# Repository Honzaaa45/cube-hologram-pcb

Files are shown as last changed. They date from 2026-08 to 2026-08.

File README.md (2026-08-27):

<div align="center">

<picture>
  <source media="(prefers-color-scheme: dark)" srcset="docs/media/banner-dark.svg">
  <source media="(prefers-color-scheme: light)" srcset="docs/media/banner-light.svg">
  CUBE — afficheur holographique Pepper's Ghost
</picture>

# CUBE

**Carte électronique d'un afficheur holographique de bureau — conçue entièrement par du code, vérifiée automatiquement.**









</div>

---

## Aperçu

Le circuit imprimé, rendu depuis les fichiers de ce dépôt. Fond transparent : lisible en thème clair comme en thème sombre.

<div align="center">
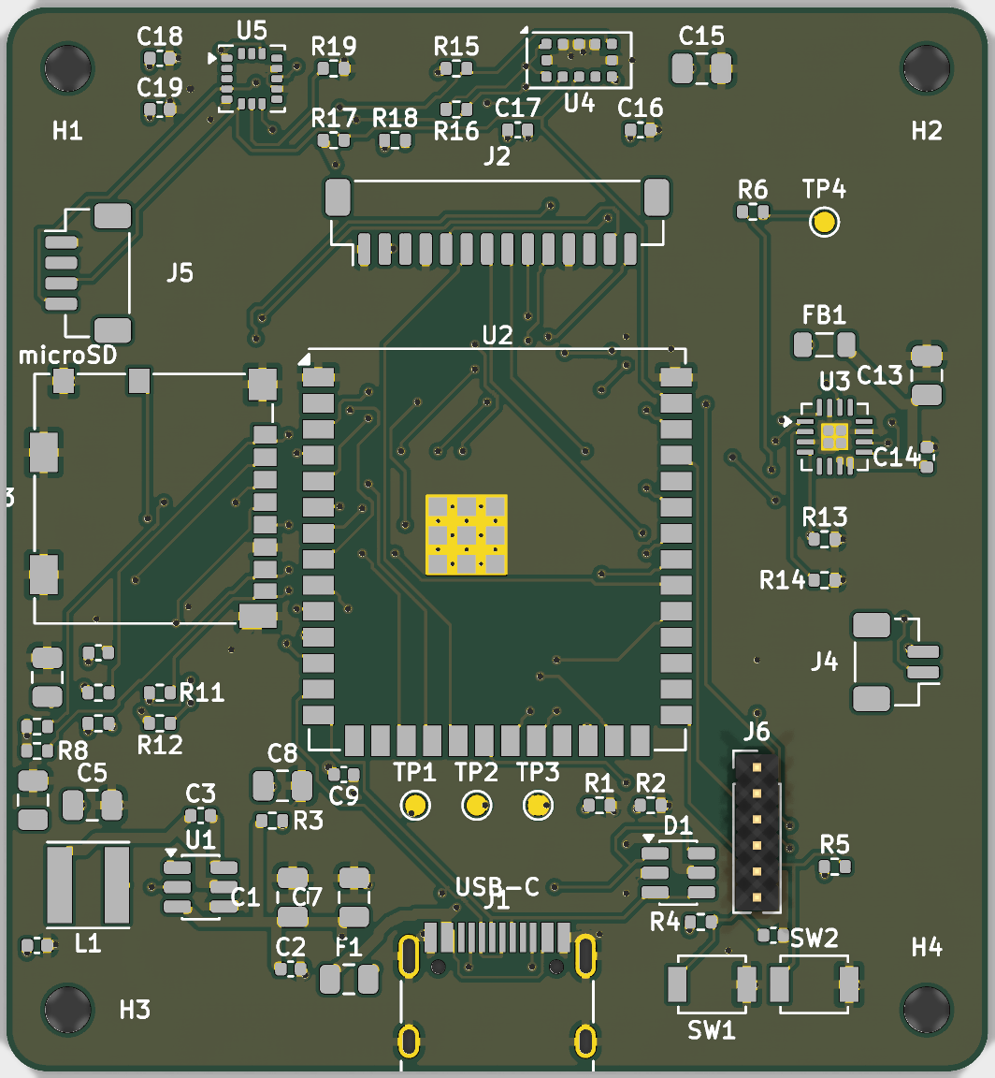
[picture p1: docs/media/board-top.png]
Carte CUBE vue de dessus
  
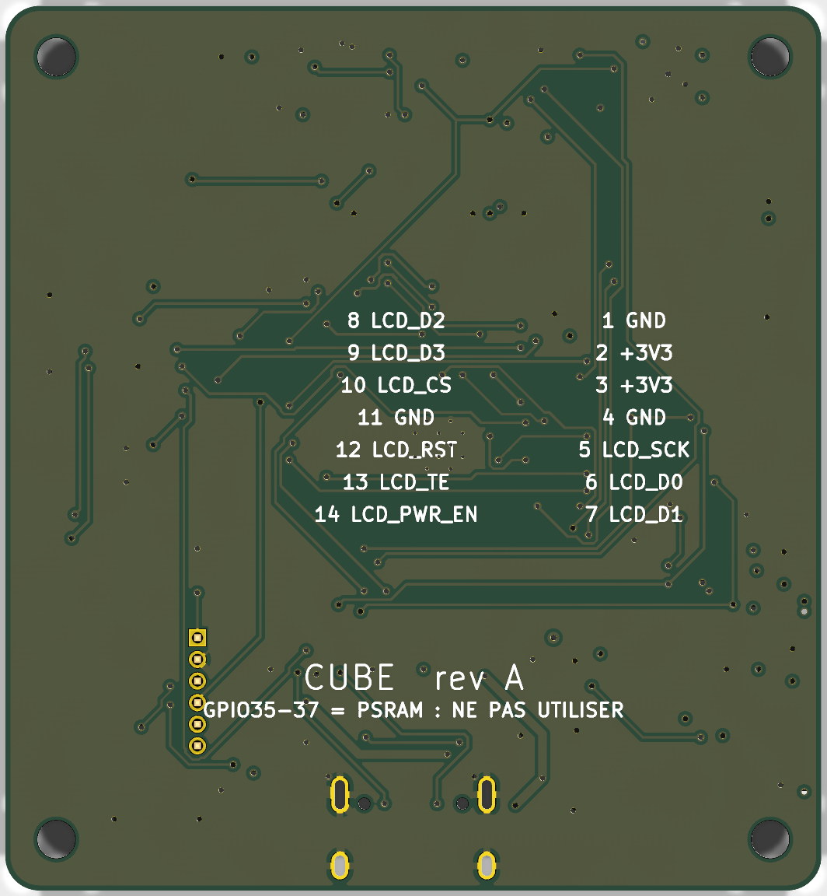
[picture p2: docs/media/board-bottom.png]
Carte CUBE vue de dessous
  
</div>

> [!NOTE]
> **La carte n'a pas encore été fabriquée.** Les images ci-dessus sont des rendus 3D produits par KiCad
> à partir des fichiers du dépôt, pas des photos. L'emplacement `docs/media/demo.gif` est réservé pour
> la démonstration du prototype physique — voir [ce qu'il reste à faire](#état-davancement).

## Pourquoi ce projet

Les afficheurs « holographiques » DIY qu'on trouve en ligne se ressemblent tous : un ESP32, un petit écran
OLED monochrome et une breadboard. Le résultat est saccadé, minuscule, et l'électronique est visible.
Ce projet répond à la même envie mais en produit final : image couleur fluide, électronique intégrée sur
une carte sur mesure, et surtout une conception **vérifiable** plutôt que dessinée à la main.

## Le principe optique

L'illusion s'appelle *Pepper's Ghost*. Une dalle posée à plat éclaire un cube séparateur de faisceau ;
la lame à 45° à l'intérieur du cube renvoie l'image vers l'observateur, qui la voit flotter dans le verre.

**La conséquence, et c'est tout le projet :** en Pepper's Ghost, **le noir de l'image est la transparence**.
Un écran LCD, dont le noir est gris, ferait flotter un rectangle lumineux autour du sujet. Un pixel AMOLED
éteint n'émet rien, donc disparaît vraiment. Ce constat commande l'ensemble des choix matériels.

## Architecture

Ce dépôt n'est pas un projet KiCad : c'est une **chaîne de génération** dont KiCad est la sortie.
`design.py` est la seule source de vérité ; tout le reste en découle et se recalcule.

```mermaid
flowchart TD
    D["design.py<br/>source unique de vérité<br/>63 composants · 46 nets · 223 connexions"]

    D --> GS["gen_sch.py"]
    D --> PL["place.py<br/>solveur de placement"]
    D --> GD["gen_docs.py"]

    PL --> RT["router.py<br/>labyrinthe Dijkstra + couture des plans"]
    RT --> CL["cleanup.py<br/>passe de finition"]
    CL --> RJ["routes.json"]
    RJ --> GP["gen_pcb.py"]
    D --> GP

    GS --> SCH["cube.kicad_sch"]
    GP --> PCB["cube.kicad_pcb"]
    PCB --> FZ["fill_zones.py<br/>remplissage des plans"]

    SCH --> V["validate.py + check_cad.py"]
    FZ --> V
    V --> OK{{"ERC 0 erreur<br/>DRC 0 violation<br/>parité 0 écart"}}

    FZ --> GF["gen_fab.py"]
    GF --> FAB["gerbers · CPL · STEP · rendus"]
    GD --> DOC["docs/CARTE.md"]

    OK -.->|"rejoué à chaque push"| CI["GitHub Actions"]
```

<details>
<summary><b>Architecture matérielle de la carte</b> (cliquer pour dérouler)</summary>

```mermaid
flowchart LR
    USB["USB-C<br/>5 V"] --> F["Fusible PPTC<br/>+ ESD USBLC6"]
    F --> BK["AP63203WU<br/>buck 2 A → 3,3 V"]
    BK --> MCU
    F -.->|"USB natif D+/D−"| MCU

    MCU["ESP32-S3-WROOM-1U<br/>N16R8<br/>16 MB flash · 8 MB PSRAM octale"]

    MCU -->|"QSPI + TE"| LCD["J2 — dalle AMOLED<br/>JST-SH 14 pts"]
    MCU -->|"SDIO 4 bits"| SD["microSD"]
    MCU -->|"I2S"| FB["Ferrite"] --> AMP["MAX98357A"] --> SPK["Haut-parleur"]
    MCU -->|"I2C"| TOF["VL53L1X<br/>0x29"]
    MCU -->|"I2C"| ACC["LIS3DH<br/>0x18"]
    MCU -->|"UART0 + BOOT/EN"| DBG["J6 — debug"]
```

</details>

## Démarrage rapide

Il faut **Python 3.9+** et **KiCad 9** installé : les scripts lisent ses bibliothèques officielles de
symboles et d'empreintes. Aucune dépendance Python à installer pour la vérification.

```bash
git clone https://github.com/Honzaaa45/cube-hologram-pcb.git
```

```bash
cd cube-hologram-pcb
```

Vérifier que la conception est cohérente (14 contrôles, ~2 s) :

```bash
python tools/validate.py
```

Rejouer l'ERC, le DRC et le contrôle de parité schéma/PCB :

```bash
python tools/check_cad.py
```

Ouvrir le projet dans KiCad :

```bash
kicad hw/cube.kicad_pro
```

<details>
<summary><b>Régénérer toute la CAO depuis <code>design.py</code></b></summary>

Le schéma et le PCB sont des **sorties**. Après avoir modifié `tools/design.py` :

```bash
python tools/gen_project.py
```

```bash
python tools/gen_sch.py
```

```bash
python tools/gen_pcb.py
```

Si le placement a changé, relancer le solveur puis le routeur (≈ 8 min) :

```bash
python tools/place.py
```

```bash
python tools/router.py
```

Puis remplir les plans de cuivre. **Cette étape n'est pas optionnelle** : sans elle, le DRC voit les
zones vides et signale à tort toutes les pastilles de masse comme non connectées.

```bash
"C:\Program Files\KiCad\9.0\bin\python.exe" tools/fill_zones.py
```

Enfin, produire les fichiers de fabrication :

```bash
python tools/gen_fab.py
```

Si KiCad n'est pas détecté automatiquement, renseignez `KICAD_SHARE` et `KICAD_CLI` — voir
[`.env.example`](.env.example).

</details>

## La carte en bref

| | |
|---|---|
| Microcontrôleur | ESP32-S3-WROOM-1U-N16R8 — 16 MB flash, **8 MB PSRAM octale**, antenne U.FL |
| Écran | connecteur QSPI générique 14 points (JST-SH 1,0 mm), **broche TE câblée** |
| Stockage | microSD en SDIO 4 bits |
| Audio | MAX98357A, ampli classe D I2S mono |
| Capteurs | VL53L1X (temps de vol) + LIS3DH (accéléromètre) |
| Alimentation | USB-C 5 V → AP63203WU, buck 2 A sortie 3,3 V fixe |
| Circuit imprimé | **48 × 52 mm**, 4 couches, 63 composants, montage sur une seule face |
| Empilage | F.Cu / plan de masse / plan +3V3 / B.Cu |

Le détail complet — table des GPIO, brochages des connecteurs, bilan de consommation, cotes pour
Fusion 360 et nomenclature — est dans **[`docs/CARTE.md`](docs/CARTE.md)**.

## Stack et arborescence

**Python 3** (bibliothèque standard uniquement pour la génération) · **KiCad 9** (bibliothèques et
`kicad-cli`) · **ruff** pour le lint · **GitHub Actions** pour la vérification continue.

```
tools/                  chaîne de génération — aucune dépendance externe
  design.py               SOURCE UNIQUE DE VÉRITÉ : composants, netlist, placement
  sexpr.py                lecteur/écrivain de S-expressions KiCad, écrit à la main
  symlib.py               accès aux bibliothèques officielles KiCad 9
  fputil.py               géométrie des empreintes (courtoisie, pastilles, rotation)
  kicadpath.py            localise KiCad sans chemin codé en dur
  place.py                solveur de placement par relaxation sous contraintes
  router.py               routeur labyrinthe (Dijkstra 8 directions) + couture des plans
  cleanup.py              passe de finition sur les liaisons restantes
  import_routes.py        recapture dans routes.json le routage fait a la main
  gen_sch.py              produit hw/cube.kicad_sch
  gen_pcb.py              produit hw/cube.kicad_pcb
  gen_project.py          produit le projet KiCad et les tables de bibliothèques
  fill_zones.py           remplit les plans avec le moteur officiel de KiCad
  gen_fab.py              gerbers, perçage, CPL, STEP, rendus, PDF
  gen_docs.py             produit docs/CARTE.md
  gen_social.py           produit l'aperçu social
  validate.py             14 contrôles de cohérence  ← lancé par la CI
  check_cad.py            verrou de non-régression ERC/DRC  ← lancé par la CI

hw/                     projet KiCad 9 (fichiers générés, mais versionnés)
  cube.kicad_pro          projet : classes de nets, règles de conception
  cube.kicad_sch          schéma, feuille A2, 7 blocs
  cube.kicad_pcb          circuit imprimé 4 couches, plans remplis
  cube.kicad_sym          symbole maison : lecteur microSD Molex 104031-0811
  routes.json             pistes et vias produits par le routeur
  erc.rpt / drc.rpt       rapports de vérification, régénérables
  fab/                    sorties prêtes à commander (gerbers, CPL, STEP, PDF)

docs/
  CARTE.md                fiche technique complète
  media/                  bannières animées, rendus, aperçu social
```

## Décisions techniques

Cinq choix qui expliquent la carte. Pour chacun : la raison, et ce qui a été écarté.

<details open>
<summary><b>1. AMOLED plutôt qu'un IPS SPI</b></summary>

En Pepper's Ghost, le noir affiché **est** la transparence. Le noir d'un LCD est un gris à environ
1000:1 de contraste : le spectateur verrait un rectangle lumineux flotter autour du sujet, et
l'illusion s'effondre. Un pixel AMOLED éteint n'émet rien.

*Écarté :* un IPS SPI (ST7789 ou GC9A01), deux à trois fois moins cher et bien plus documenté. Aucun
gain de fluidité ni de résolution ne compense un fond visible.
</details>

<details>
<summary><b>2. Module WROOM-1U plutôt que le MINI-1, réputé plus petit</b></summary>

Mesures faites avant de trancher : WROOM-1U = 18,0 × 19,2 mm (346 mm²), MINI-1 = 15,4 × 20,5 mm
(316 mm²). Le MINI-1 n'est que **9 % plus petit en surface** — et il est 1,3 mm **plus long**. En
échange on perdrait la PSRAM octale, donc la moitié de la bande passante disponible pour un
framebuffer. De toute façon, ce n'est pas le module qui dimensionne la carte : ce sont l'USB-C, le
connecteur écran et les trous de fixation.

*Écarté :* ESP32-S3-MINI-1-N8 (8 MB flash, aucune PSRAM) et la puce nue ESP32-S3FH4R2 (49 mm², mais
elle impose design RF, quartz, antenne accordée et recertification).
</details>

<details>
<summary><b>3. Un convertisseur à découpage, pas un régulateur linéaire</b></summary>

Bilan en pointe du rail 3,3 V : ESP32-S3 en émission WiFi (355 mA) + dalle AMOLED plein blanc
(~250 mA) + écriture microSD (~100 mA) ≈ 900 mA. Un LDO 5 V → 3,3 V y dissiperait environ 1 W —
dans un boîtier fermé et opaque, à côté d'un capteur de distance.

*Écarté :* un LDO 1 A type AP7361C, plus simple (trois composants au lieu de six) et sans bruit de
découpage. Le calcul thermique tranche.
</details>

<details>
<summary><b>4. L'amplificateur audio alimenté en 3,3 V, pas en 5 V</b></summary>

Le MAX98357A accepte 2,5 à 5,5 V, et 5 V donnerait plus de puissance acoustique. Mais ses seuils
logiques se réfèrent à son alimentation : piloter en 3,3 V une puce alimentée en 5 V place les
niveaux I2S dans une zone non garantie. La carte l'alimente donc en 3,3 V, derrière une perle de
ferrite qui isole son rail de celui du microcontrôleur.

*Écarté :* 5 V avec un adaptateur de niveau (composant et surface en plus, pour une puissance dont un
objet de bureau n'a pas l'usage).
</details>

<details>
<summary><b>5. Une CAO générée par code plutôt que dessinée à la main</b></summary>

C'est le choix structurant du dépôt. `design.py` décrit l'intention ; les scripts produisent le
schéma et le circuit imprimé ; puis un script **compare la netlist réellement exportée par KiCad à
cette intention, connexion par connexion** — 223 sur 223, zéro divergence. La CI rejoue l'ERC, le DRC
et le contrôle de parité à chaque push.

Le bénéfice n'est pas la vitesse : dessiner à la main aurait été plus rapide au départ. C'est de
pouvoir **prouver** que le schéma est juste, et de tout régénérer après un changement sans reprendre
le travail. C'est aussi ce qui a permis de détecter, pendant le développement, que la table des GPIO
documentait `LCD_SCK` là où le netlist portait `LCD_SCK_MCU` — une résistance série séparait les deux.

*Écarté :* KiCad en interactif, l'approche normale et parfaitement légitime. Elle ne donne aucun
moyen de démontrer la cohérence, ni de rejouer la conception.
</details>

## État d'avancement

**Fait et vérifié :**

| Contrôle | Résultat |
|---|---|
| ERC du schéma | **0 erreur** (1 avertissement connu, documenté ci-dessous) |
| Netlist exportée comparée à l'intention | **223 / 223 connexions, 0 divergence** |
| Parité schéma ↔ PCB, vérifiée par KiCad | **0 écart** |
| Placement (contours de courtoisie) | **0 chevauchement**, toutes les pastilles sur la carte |
| DRC du circuit imprimé | **0 violation** |
| Routage | **223 / 223 connexions** |
| Sorties de fabrication | gerbers 4 couches, perçage, CPL, STEP, rendus, PDF |

L'unique avertissement ERC : le pad thermique du MAX98357A est typé « Unspecified » dans la
bibliothèque KiCad officielle et relié à GND. Le comportement est correct, c'est le typage amont qui
est imprécis.

**Intégration continue :** le workflow [`.github/workflows/ci.yml`](.github/workflows/ci.yml) rejoue à
chaque push le lint, la validation de la netlist, puis l'ERC, le DRC et le contrôle de parité sur une
installation KiCad 9 fraîche. Les commandes qu'il exécute sont exactement `python tools/validate.py`
et `python tools/check_cad.py` : elles se lancent à l'identique en local, et c'est là qu'ont été
obtenus les résultats du tableau ci-dessus.

**Routage terminé.** Les 4 dernières liaisons — autour du LIS3DH, boîtier LGA-16 au pas de 0,5 mm —
ont été tirées à la main dans Pcbnew, puis réinjectées dans `hw/routes.json` par
`tools/import_routes.py` : le routage manuel fait désormais partie du pipeline et survit à une
régénération. Restent 8 avertissements de sérigraphie purement cosmétiques (texte rogné là où il
croise une pastille ou le bord), sans effet fonctionnel.

**Limites connues — à lire avant de vous en servir :**

- ⚠️ **La carte n'a jamais été fabriquée ni testée physiquement.** Tout ce qui est affirmé ici est
  vérifié *en CAO*. Une revue humaine reste indispensable avant de commander.
- Le **firmware n'existe pas** : ce dépôt ne contient que le matériel et sa chaîne de génération.
- Le **boîtier n'est pas modélisé** ; `docs/CARTE.md` fournit les cotes nécessaires pour Fusion 360.
- Le routeur maison ne fait **pas de rip-up local**, seulement un réordonnancement global sur quatre
  passes. C'est ce qui explique les 4 liaisons restantes.
- La chaîne est **testée sous Windows** avec KiCad 9.0.7. La détection de KiCad gère Linux et macOS
  mais n'y a pas été éprouvée ; la CI, elle, tourne bien sous Ubuntu.

## Licences

Deux licences, parce que ce dépôt contient deux natures de travail :

- **Code** (`tools/`, CI, scripts) — [MIT](LICENSE).
- **Matériel** (`hw/`, schéma, circuit imprimé, fichiers de fabrication) —
  [CERN-OHL-S-2.0](LICENSE-HARDWARE), la licence matérielle libre fortement réciproque du CERN : qui
  distribue un produit dérivé de cette carte doit en publier les sources de conception.

## Auteur

**Honza** — [@Honzaaa45](https://github.com/Honzaaa45)
Étudiant en BUT GEII, parcours Automatisme et Informatique Industrielle.

Les contributions sont bienvenues, en particulier sur le routeur : voir
[CONTRIBUTING.md](CONTRIBUTING.md).

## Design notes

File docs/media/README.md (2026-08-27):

# Ressources visuelles

| Fichier | Origine | Régénération |
|---|---|---|
| `banner-light.svg` / `banner-dark.svg` | Bannière animée (SMIL), écrite à la main. Schéma optique Pepper's Ghost : dalle, cube séparateur, lame à 45°, rayons, image virtuelle. | manuelle |
| `board-top.png` / `board-bottom.png` | Rendus 3D KiCad, **fond transparent** pour rester lisibles sur les deux thèmes GitHub. | `python tools/gen_fab.py` |
| `social.png` | Aperçu social 1280 × 640 (GitHub, LinkedIn, Slack). | `python tools/gen_social.py` |
| `demo.gif` | **Manquant.** Réservé à la démonstration du prototype physique. | à filmer — voir ci-dessous |

## Ce qu'il faut filmer pour `demo.gif`

La carte n'est pas encore fabriquée : cette démonstration ne peut pas exister aujourd'hui.
Quand le prototype fonctionnera, capturer une boucle de **6 à 10 secondes**, en **800 × 600** ou moins,
sous **8 Mo** (limite d'affichage confortable sur GitHub) :

1. **Plan large, 2 s** — l'objet posé sur un bureau, boîtier fermé, dans une pièce peu éclairée.
   C'est l'obscurité relative qui rend l'illusion crédible.
2. **Plan serré sur le cube, 4 s** — l'animation qui flotte à l'intérieur. Filmer légèrement de côté
   puis se déplacer : c'est le déplacement du point de vue qui prouve que l'image flotte réellement,
   une vue fixe pourrait passer pour un autocollant.
3. **Fin, 2 s** — la main qui s'approche pour déclencher le capteur de distance, si cette fonction est
   implémentée dans le firmware.

Contraintes de prise de vue : trépied obligatoire (l'illusion supporte mal le tremblement), pas de
lumière directe sur la face avant du cube, et **ne pas filmer en contre-jour** — le halo parasite
détruirait le noir dont dépend tout l'effet.

Conversion depuis une vidéo :

```bash
ffmpeg -i demo.mp4 -vf "fps=15,scale=800:-1:flags=lanczos,split[a][b];[a]palettegen[p];[b][p]paletteuse" -loop 0 docs/media/demo.gif
```

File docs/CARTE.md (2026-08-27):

# CUBE — carte electronique

Carte mere de l'afficheur holographique Pepper's Ghost.

| | |
|---|---|
| MCU | ESP32-S3-WROOM-1U-N16R8 — 16 MB flash, 8 MB PSRAM **octale**, antenne U.FL |
| Ecran | connecteur QSPI generique 14 points, JST-SH 1,0 mm (J2) |
| Stockage | microSD en **SDIO 4 bits** (J3) |
| Audio | MAX98357A, ampli classe D I2S mono (U3) |
| Capteurs | VL53L1X (ToF, 0x29) + LIS3DH (accelerometre, 0x18) |
| Alimentation | USB-C 5 V -> AP63203WU, buck 2 A sortie 3,3 V fixe |
| Carte | 48.0 x 52.0 mm, **4 couches**, composants sur la face avant uniquement |

## Empilage

| Couche | Role |
|---|---|
| F.Cu | signaux + plan de masse de remplissage |
| In1.Cu | **plan de masse plein** — reference de retour du bus QSPI |
| In2.Cu | **plan +3V3** |
| B.Cu | signaux + plan de masse de remplissage |

Le bus QSPI de l'ecran est route sur F.Cu, directement au-dessus du plan de
masse In1 : c'est ce qui donne un chemin de retour court et propre a 80 MHz.

## Reperes mecaniques

Le repere du plan de masse (coordonnees KiCad) :

* `y = 100.0` — **avant** du boitier : le VL53L1X (U4) vise vers le haut, a
  travers une petite fenetre transparente aux infrarouges, devant l'ecran.
* `y = 152.0` — **arriere** : sortie USB-C.
* `x = 100.0` — **flanc gauche** : trappe microSD.
* 4 trous M2 (103.0 / 145.0 en X, 103.0 / 149.0 en Y), inserts a chaud
  recommandes cote boitier.

## Cotes pour le boitier (Fusion 360)

Origine = **coin haut-gauche de la carte** (le coin avant-gauche), axe X vers la droite, axe Y vers l'arriere.

* Contour : rectangle **48 x 52 mm**, coins arrondis R2.0 mm.
* Epaisseur du circuit imprime : 1,6 mm.
* Trous M2 (diametre 2,2 mm) a **3,0 mm** de chaque bord, soit (3,0 / 3,0), (45.0 / 3,0), (3,0 / 49.0), (45.0 / 49.0).
* La prise USB-C **deborde de 1.7 mm** au-dela du bord arriere : prevoir la decoupe correspondante dans le boitier.

| Ref | Role | Centre (x, y) | Emprise X | Emprise Y |
|---|---|---|---|---|
| J1 | USB-C | 24.00, 49.50 | 18.68 .. 29.32 | 44.23 .. 53.65 |
| J3 | microSD | 7.20, 24.00 | 0.65 .. 13.70 | 17.16 .. 30.84 |
| J2 | ECRAN QSPI | 24.00, 10.50 | 15.10 .. 32.90 | 7.90 .. 13.10 |
| J4 | HP | 43.50, 32.00 | 40.90 .. 46.10 | 29.10 .. 34.90 |
| J5 | I2C EXT | 4.00, 13.00 | 1.40 .. 6.60 | 9.10 .. 16.90 |
| J6 | DEBUG | 36.70, 37.15 | 35.15 .. 38.25 | 36.01 .. 44.64 |
| U2 | ESP32-S3-WROOM-1U-N16R8 | 24.00, 26.50 | 14.25 .. 33.75 | 16.65 .. 36.80 |
| U4 | VL53L1X | 28.00, 2.60 | 25.30 .. 30.70 | 1.10 .. 4.10 |
| SW1 | RESET | 34.50, 47.75 | 32.10 .. 36.90 | 46.10 .. 49.40 |
| SW2 | BOOT | 39.50, 47.75 | 37.10 .. 41.90 | 46.10 .. 49.40 |

Hauteurs a prevoir au-dessus de la carte (les plus contraignantes) :

| Composant | Hauteur approx. |
|---|---|
| Connecteurs JST-SH verticaux (J2, J4, J5) | ~4,3 mm nu, ~6 mm avec le connecteur femelle engage |
| Module ESP32-S3-WROOM-1U | 3,2 mm + le connecteur U.FL et son cable |
| Prise USB-C | 3,2 mm |
| Inductance L1 | 2,0 mm |
| Lecteur microSD | 1,9 mm |

Compter **8 mm de degagement** au-dessus de la carte pour etre tranquille.

> Le VL53L1X (U4) est en surface et **vise vers le haut**, perpendiculairement
> a la carte. Il lui faut une petite fenetre transparente aux infrarouges dans
> le plateau superieur, en avant de l'ecran, avec un entrefer maitrise. Si cela
> gene le design du boitier, ne pas monter U4 et brancher a la place un module
> ToF tout fait sur le port J5, positionne librement.

## Affectation des GPIO

| GPIO | Broche module | Net | Role |
|---|---|---|---|
| IO12 | 20 | LCD_SCK_MCU | Horloge QSPI, devient LCD_SCK apres R6 |
| IO11 | 19 | LCD_D0 | Donnee QSPI 0 |
| IO13 | 21 | LCD_D1 | Donnee QSPI 1 |
| IO14 | 22 | LCD_D2 | Donnee QSPI 2 |
| IO10 | 18 | LCD_D3 | Donnee QSPI 3 |
| IO9 | 17 | LCD_CS | Selection ecran |
| IO8 | 12 | LCD_RST | Reset ecran |
| IO18 | 11 | LCD_TE | Tearing Effect - synchro anti-dechirure |
| IO17 | 10 | LCD_PWR_EN | Activation alimentation dalle |
| IO39 | 32 | SD_CLK | Horloge SDIO |
| IO38 | 31 | SD_CMD | Commande SDIO |
| IO40 | 33 | SD_D0 | Donnee SDIO 0 |
| IO41 | 34 | SD_D1 | Donnee SDIO 1 |
| IO42 | 35 | SD_D2 | Donnee SDIO 2 |
| IO21 | 23 | SD_D3 | Donnee SDIO 3 |
| IO47 | 24 | SD_DET | Detection de carte |
| IO5 | 5 | I2S_BCLK | Horloge bit I2S |
| IO6 | 6 | I2S_LRCLK | Horloge mot I2S |
| IO7 | 7 | I2S_DOUT | Donnee I2S |
| IO15 | 8 | AMP_EN | Activation ampli (bas = eteint) |
| IO1 | 39 | I2C_SDA | I2C donnee |
| IO2 | 38 | I2C_SCL | I2C horloge |
| IO16 | 9 | TOF_XSHUT | Reset du VL53L1X |
| IO4 | 4 | TOF_INT | Interruption ToF |
| IO48 | 25 | ACC_INT1 | Interruption accelerometre |
| IO19 | 13 | USB_D- | USB natif |
| IO20 | 14 | USB_D+ | USB natif |
| IO43 | 37 | UART_TX | Console de debug |
| IO44 | 36 | UART_RX | Console de debug |
| IO0 | 27 | BOOT | Strapping - bouton BOOT |
| IO35 | 28 | -- INTERDIT | PSRAM octale (N16R8) |
| IO36 | 29 | -- INTERDIT | PSRAM octale (N16R8) |
| IO37 | 30 | -- INTERDIT | PSRAM octale (N16R8) |
| IO3 | 15 | libre | Strapping JTAG - laisse non connecte |
| IO45 | 26 | libre | Strapping VDD_SPI - laisse non connecte |
| IO46 | 16 | libre | Strapping log ROM - laisse non connecte |

> **GPIO35, 36 et 37 sont consommes par la PSRAM octale du N16R8.** Ils ne
> sont sortis nulle part sur cette carte et ne doivent jamais etre configures
> par le firmware. GPIO3, 45 et 46 sont des broches de strapping, laissees
> volontairement non connectees.

## J2 — connecteur ecran QSPI (JST-SH 1,0 mm, 14 points)

| Broche | Signal |
|---|---|
| 1 | GND |
| 2 | +3V3 |
| 3 | +3V3 |
| 4 | GND |
| 5 | LCD_SCK |
| 6 | LCD_D0 |
| 7 | LCD_D1 |
| 8 | LCD_D2 |
| 9 | LCD_D3 |
| 10 | LCD_CS |
| 11 | GND |
| 12 | LCD_RST |
| 13 | LCD_TE |
| 14 | LCD_PWR_EN |

L'ordre a ete choisi pour la qualite du signal : alimentation et masse
groupees en tete, les quatre lignes de donnees et l'horloge au milieu encadrees
par des masses, les commandes lentes en fin de connecteur.

`LCD_TE` est la broche *Tearing Effect* de la dalle. La cabler est ce qui
permet de synchroniser l'envoi d'une trame sur le balayage et d'obtenir zero
dechirure. C'est le detail qui separe un rendu propre d'un rendu « presque ».

`R6` est une resistance serie de 0 ohm sur `LCD_SCK`. Si l'horloge sonne sur
un cable ruban un peu long, la remplacer par 22 ohms.

## Autres connecteurs

| Ref | Nom | Type | Brochage |
|---|---|---|---|
| J4 | HP | JST-SH 2 pts | 1 = SPK_P, 2 = SPK_N. Sortie pontee : ne jamais relier une sortie a la masse. |
| J5 | I2C EXT | JST-SH 4 pts | 1 = GND, 2 = +3V3, 3 = SDA, 4 = SCL. Brochage compatible Qwiic / STEMMA-QT. |
| J6 | DEBUG | Barrette 1,27 mm 6 pts | 1 = +3V3, 2 = GND, 3 = TXD0, 4 = RXD0, 5 = IO0, 6 = EN. |

## Bilan de consommation

| Consommateur | Typique | Pointe |
|---|---|---|
| ESP32-S3 (WiFi au repos) | 40–100 mA | 355 mA en emission |
| Dalle AMOLED | 80–150 mA | ~250 mA plein blanc |
| microSD en ecriture | 20 mA | 100 mA |
| MAX98357A | 10 mA | 200 mA en crete audio |
| VL53L1X + LIS3DH | < 20 mA | — |
| **Total rail 3,3 V** | **~250 mA** | **~900 mA** |

L'AP63203WU tient 2 A : la marge est confortable. C'est un buck et non un
regulateur lineaire, ce qui compte reellement dans un boitier ferme et opaque :
un LDO aurait dissipe pres de 1 W en pointe.

`FB1` (perle de ferrite 600 ohms) isole le rail de l'ampli du rail du MCU.
L'ampli est alimente en **3,3 V et non en 5 V** : les niveaux logiques I2S sont
ainsi identiques a ceux du MCU, ce qui evite tout probleme de seuil VIH.
La puissance reste largement suffisante pour un objet de bureau.

## Notes de fabrication

* Procede JLCPCB 4 couches standard : piste mini 0,127 mm, isolation 0,127 mm,
  percage mini 0,2 mm. Le routage respecte 0,13 mm d'isolation.
* Les vias thermiques sous le module ESP32 percent a 0,2 mm : c'est l'empreinte
  officielle KiCad, ne pas la modifier.
* `R14` est volontairement **non montee** (choix de gain de l'ampli : vide = 9 dB).
* `R19` fixe l'adresse I2C de l'accelerometre : 0 ohm vers GND = 0x18.
* Assemblage sur une seule face : tout est sur F.Cu.

## Ce qu'il reste a router

Aucune liaison en attente : la carte est entierement routee.

## Nomenclature

| References | Valeur | MPN | Empreinte | Qte |
|---|---|---|---|---|
| C2, C3, C6, C9, C12, C14, C16, C17, C18, C19 | 100nF | — | C_0402_1005Metric | 10 |
| R4, R5, R7, R8, R9, R10, R11, R12, R15, R16 | 10k | — | R_0402_1005Metric | 10 |
| C7, C4, C5, C8, C13 | 22uF/10V | — | C_0805_2012Metric | 5 |
| H1, H2, H3, H4 | M2 | — | MountingHole_2.2mm_M2 | 4 |
| R6, R19 | 0R | — | R_0402_1005Metric | 2 |
| R3, R13 | 100k | — | R_0402_1005Metric | 2 |
| C11, C15 | 10uF/10V | — | C_0805_2012Metric | 2 |
| R17, R18 | 4.7k | — | R_0402_1005Metric | 2 |
| R1, R2 | 5.1k | — | R_0402_1005Metric | 2 |
| TP2 | +3V3 | — | TestPoint_Pad_D1.0mm | 1 |
| TP1 | +5V | — | TestPoint_Pad_D1.0mm | 1 |
| F1 | 1.1A | MF-MSMF110-2 | Fuse_0805_2012Metric | 1 |
| C1 | 10uF/25V | — | C_0805_2012Metric | 1 |
| C10 | 1uF | — | C_0402_1005Metric | 1 |
| L1 | 2.2uH/3A | NR4018T2R2M | L_Taiyo-Yuden_NR-40xx | 1 |
| FB1 | 600R@100MHz | BLM21PG600SN1D | L_0805_2012Metric | 1 |
| U1 | AP63203WU | AP63203WU-7 | TSOT-23-6 | 1 |
| SW2 | BOOT | B3U-1000P | SW_SPST_B3U-1000P | 1 |
| J6 | DEBUG | — | PinHeader_1x06_P1.27mm_Vertical | 1 |
| R14 | DNP | — | R_0402_1005Metric | 1 |
| J2 | ECRAN QSPI | BM14B-SRSS-TB | JST_SH_BM14B-SRSS-TB_1x14-1MP_P1.00mm_Vertical | 1 |
| U2 | ESP32-S3-WROOM-1U-N16R8 | ESP32-S3-WROOM-1U-N16R8 | ESP32-S3-WROOM-1U | 1 |
| TP3 | GND | — | TestPoint_Pad_D1.0mm | 1 |
| J4 | HP | BM02B-SRSS-TB | JST_SH_BM02B-SRSS-TB_1x02-1MP_P1.00mm_Vertical | 1 |
| J5 | I2C EXT | BM04B-SRSS-TB | JST_SH_BM04B-SRSS-TB_1x04-1MP_P1.00mm_Vertical | 1 |
| TP4 | LCD_SCK | — | TestPoint_Pad_D1.0mm | 1 |
| U5 | LIS3DH | LIS3DHTR | LGA-16_3x3mm_P0.5mm_LayoutBorder3x5y | 1 |
| U3 | MAX98357A | MAX98357AETE+T | TQFN-16-1EP_3x3mm_P0.5mm_EP1.23x1.23mm | 1 |
| SW1 | RESET | B3U-1000P | SW_SPST_B3U-1000P | 1 |
| J1 | USB-C | TYPE-C-31-M-12 | USB_C_Receptacle_HRO_TYPE-C-31-M-12 | 1 |
| D1 | USBLC6-2SC6 | USBLC6-2SC6 | SOT-23-6 | 1 |
| U4 | VL53L1X | VL53L1CXV0FY/1 | ST_VL53L1x | 1 |
| J3 | microSD | 104031-0811 | microSD_HC_Molex_104031-0811 | 1 |

**Total : 63 composants, 33 references distinctes.**

## Pieces a commander hors PCB

| Piece | Note |
|---|---|
| Dalle AMOLED QSPI + carte porteuse | 1,43" rond 466x466 (CO5300) ou 1,8" 368x448 (SH8601). **Verifier que la broche TE est sortie** sur le connecteur. |
| Cable JST-SH 1,0 mm 14 points | a confectionner selon le brochage de J2 ci-dessus |
| Antenne U.FL / IPEX 2,4 GHz | le WROOM-1U n'a pas d'antenne integree |
| Haut-parleur 8 ohms, 1 W | + cable JST-SH 2 points |
| Cube separateur 50/50 | 25 mm minimum ; voir les compromis dans la discussion |
| Vis M2 + inserts a chaud | 4 exemplaires |

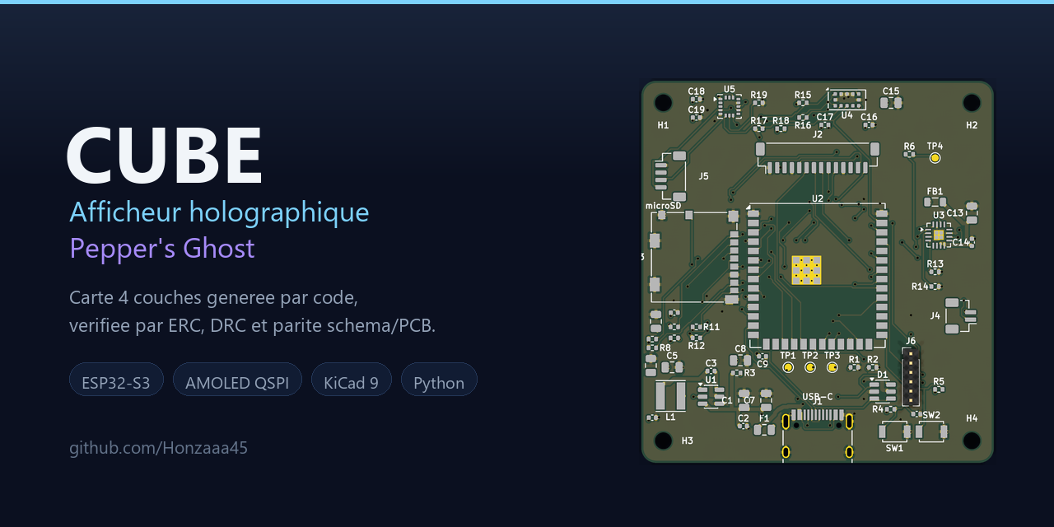
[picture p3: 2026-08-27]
docs/media/social.png

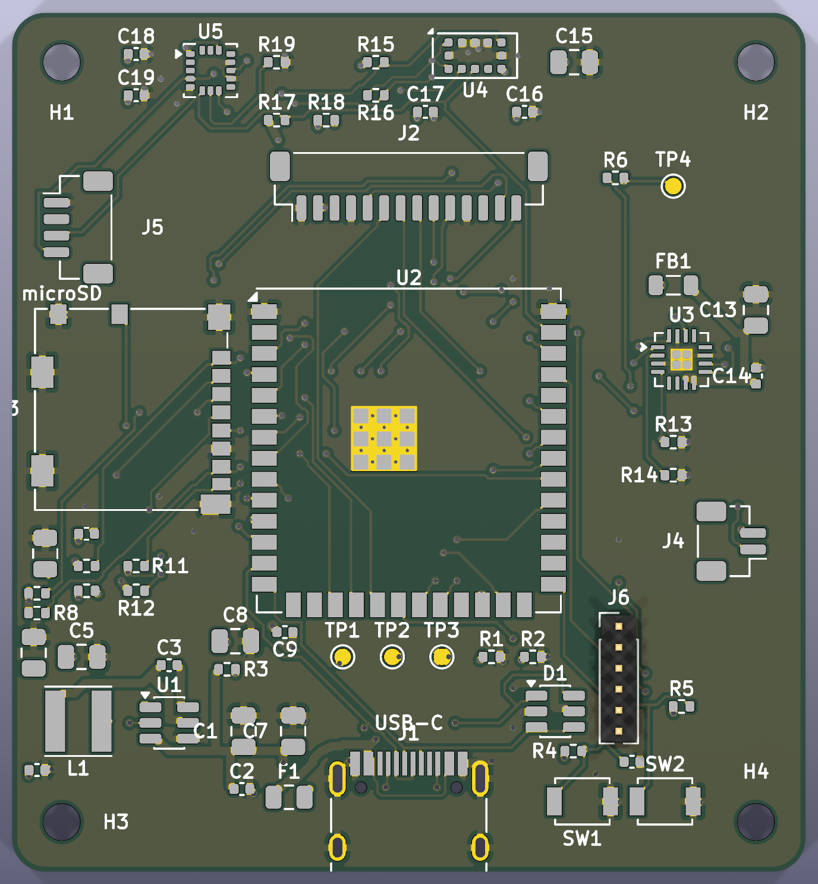
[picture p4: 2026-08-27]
hw/fab/cube-dessus.png

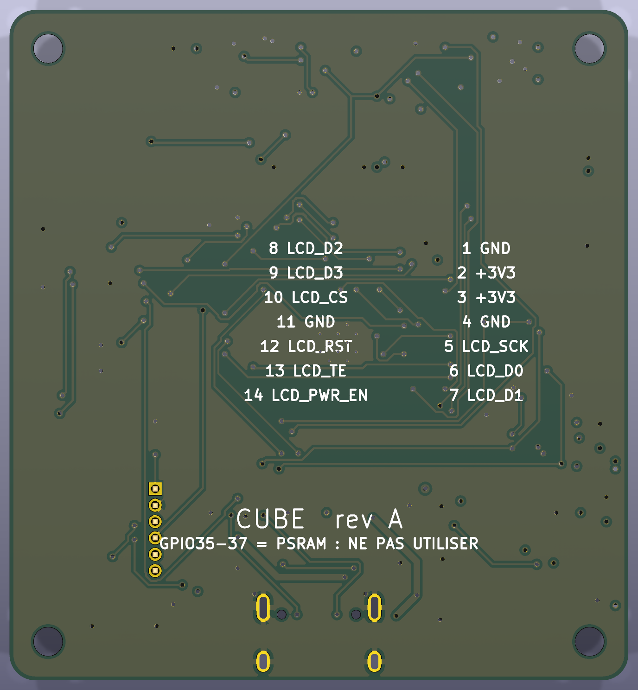
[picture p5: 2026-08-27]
hw/fab/cube-dessous.png

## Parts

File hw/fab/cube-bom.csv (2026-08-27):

Reference | Value | Footprint | MPN | Description | QUANTITY
C1 | 10uF/25V | Capacitor_SMD:C_0805_2012Metric |  | Decouplage entree buck | 1
C2,C3,C6,C9,C12,C14,C16-C19 | 100nF | Capacitor_SMD:C_0402_1005Metric |  | Condensateur bootstrap SW->BST,Decouplage AVDDVCSEL,Decouplage HF 3V3 du module,Decouplage HF AVDD ToF,Decouplage HF VDD ampli,Decouplage HF VDD carte SD,Decouplage HF entree buck,Decouplage HF sortie 3.3 V,Decouplage VDD accelero,Decouplage VDD_IO accelero | 10
C4,C5,C7,C8,C13 | 22uF/10V | Capacitor_SMD:C_0805_2012Metric |  | Reservoir 3V3 du module,Reservoir 5 V,Reservoir VDD ampli,Reservoir sortie 3.3 V | 5
C10 | 1uF | Capacitor_SMD:C_0402_1005Metric |  | Retard RC sur EN | 1
C11,C15 | 10uF/10V | Capacitor_SMD:C_0805_2012Metric |  | Reservoir AVDD ToF,Reservoir VDD carte SD | 2
D1 | USBLC6-2SC6 | Package_TO_SOT_SMD:SOT-23-6 | USBLC6-2SC6 | Reseau de protection ESD 2 lignes USB | 1
F1 | 1.1A | Fuse:Fuse_0805_2012Metric | MF-MSMF110-2 | Fusible reamorcable PPTC, Ihold 1.1 A | 1
FB1 | 600R@100MHz | Inductor_SMD:L_0805_2012Metric | BLM21PG600SN1D | Perle de ferrite : isole le rail de l'ampli | 1
J1 | USB-C | Connector_USB:USB_C_Receptacle_HRO_TYPE-C-31-M-12 | TYPE-C-31-M-12 | Prise USB-C 2.0, 16 pts, montage CMS | 1
J2 | ECRAN QSPI | Connector_JST:JST_SH_BM14B-SRSS-TB_1x14-1MP_P1.00mm_Vertical | BM14B-SRSS-TB | Connecteur ecran AMOLED QSPI, JST-SH 1.0 mm 14 pts | 1
J3 | microSD | Connector_Card:microSD_HC_Molex_104031-0811 | 104031-0811 | Lecteur microSD push-pull avec detection de carte | 1
J4 | HP | Connector_JST:JST_SH_BM02B-SRSS-TB_1x02-1MP_P1.00mm_Vertical | BM02B-SRSS-TB | Sortie haut-parleur 4-8 ohms | 1
J5 | I2C EXT | Connector_JST:JST_SH_BM04B-SRSS-TB_1x04-1MP_P1.00mm_Vertical | BM04B-SRSS-TB | Port I2C deporte (compatible Qwiic/STEMMA-QT) | 1
J6 | DEBUG | Connector_PinHeader_1.27mm:PinHeader_1x06_P1.27mm_Vertical |  | UART0 + BOOT + EN (secours si USB natif indisponible) | 1
L1 | 2.2uH/3A | Inductor_SMD:L_Taiyo-Yuden_NR-40xx | NR4018T2R2M | Inductance de puissance blindee 4x4 mm | 1
R1,R2 | 5.1k | Resistor_SMD:R_0402_1005Metric |  | Rd CC1 (role device),Rd CC2 (role device) | 2
R3,R13 | 100k | Resistor_SMD:R_0402_1005Metric |  | Rappel bas SD_MODE : ampli eteint au boot,Tirage EN du buck vers VIN | 2
R4,R5,R7-R12,R15,R16 | 10k | Resistor_SMD:R_0402_1005Metric |  | Tirage INT (drain ouvert),Tirage SD_CMD,Tirage SD_D0,Tirage SD_D1,Tirage SD_D2,Tirage SD_D3,Tirage XSHUT,Tirage detection de carte,Tirage haut de EN,Tirage haut de IO0 (BOOT) | 10
R6,R19 | 0R | Resistor_SMD:R_0402_1005Metric |  | Adresse accelero : 0R vers GND = 0x18, vers +3V3 = 0x19,Serie sur LCD_SCK - monter 22R si sonnerie | 2
R14 | DNP | Resistor_SMD:R_0402_1005Metric |  | Selection de gain : vide=9 dB, 100k vers GND=12 dB | 1
R17,R18 | 4.7k | Resistor_SMD:R_0402_1005Metric |  | Tirage I2C SCL,Tirage I2C SDA | 2
SW1 | RESET | Button_Switch_SMD:SW_SPST_B3U-1000P | B3U-1000P | Bouton RESET (EN vers GND) | 1
SW2 | BOOT | Button_Switch_SMD:SW_SPST_B3U-1000P | B3U-1000P | Bouton BOOT (IO0 vers GND) | 1
U1 | AP63203WU | Package_TO_SOT_SMD:TSOT-23-6 | AP63203WU-7 | Buck synchrone 2 A, 1.1 MHz, sortie 3.3 V fixe | 1
U2 | ESP32-S3-WROOM-1U-N16R8 | RF_Module:ESP32-S3-WROOM-1U | ESP32-S3-WROOM-1U-N16R8 | MCU WiFi/BLE, 16 MB flash, 8 MB PSRAM octale, antenne U.FL | 1
U3 | MAX98357A | Package_DFN_QFN:TQFN-16-1EP_3x3mm_P0.5mm_EP1.23x1.23mm | MAX98357AETE+T | Ampli classe D I2S mono 3.2 W | 1
U4 | VL53L1X | Sensor_Distance:ST_VL53L1x | VL53L1CXV0FY/1 | Telemetre ToF laser 4 m, I2C 0x29 | 1
U5 | LIS3DH | Package_LGA:LGA-16_3x3mm_P0.5mm_LayoutBorder3x5y | LIS3DHTR | Accelerometre 3 axes, I2C 0x18 (SDO=GND) | 1

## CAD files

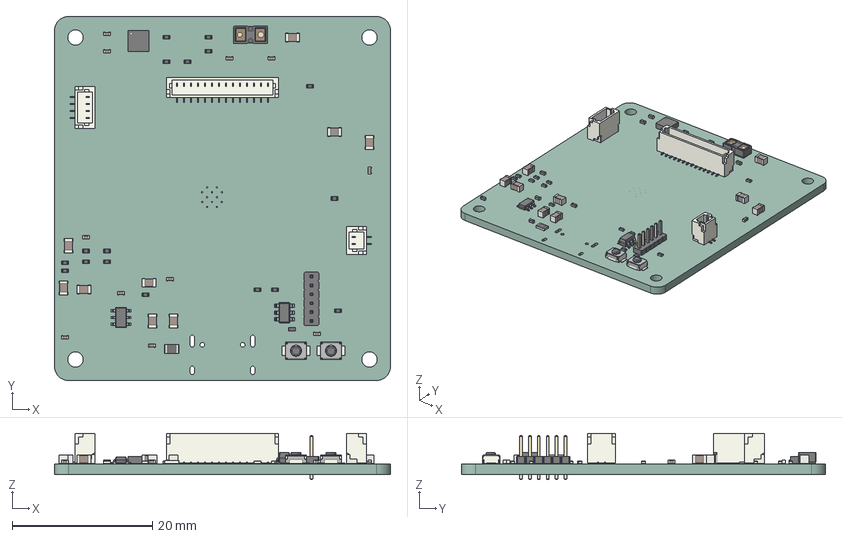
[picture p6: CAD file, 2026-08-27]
hw/fab/cube.step
48.0 x 52.0 x 6.62 mm
C_0402_1005Metric x 11
Fuse_0805_2012Metric
R_0402_1005Metric x 18
C_0805_2012Metric x 8
L_0805_2012Metric
JST_SH_BM02B-SRSS-TB_1x02-1MP_P1.00mm_Vertical
JST_SH_BM14B-SRSS-TB_1x14-1MP_P1.00mm_Vertical
TSOT-23-6
SW_SPST_B3U-1000P x 2
PinHeader_1x06_P1.27mm_Vertical
ST_VL53L1x
LGA-16_3x3mm_P0.5mm_LayoutBorder3x5y
SOT-23-6
JST_SH_BM04B-SRSS-TB_1x04-1MP_P1.00mm_Vertical
cube_PCB

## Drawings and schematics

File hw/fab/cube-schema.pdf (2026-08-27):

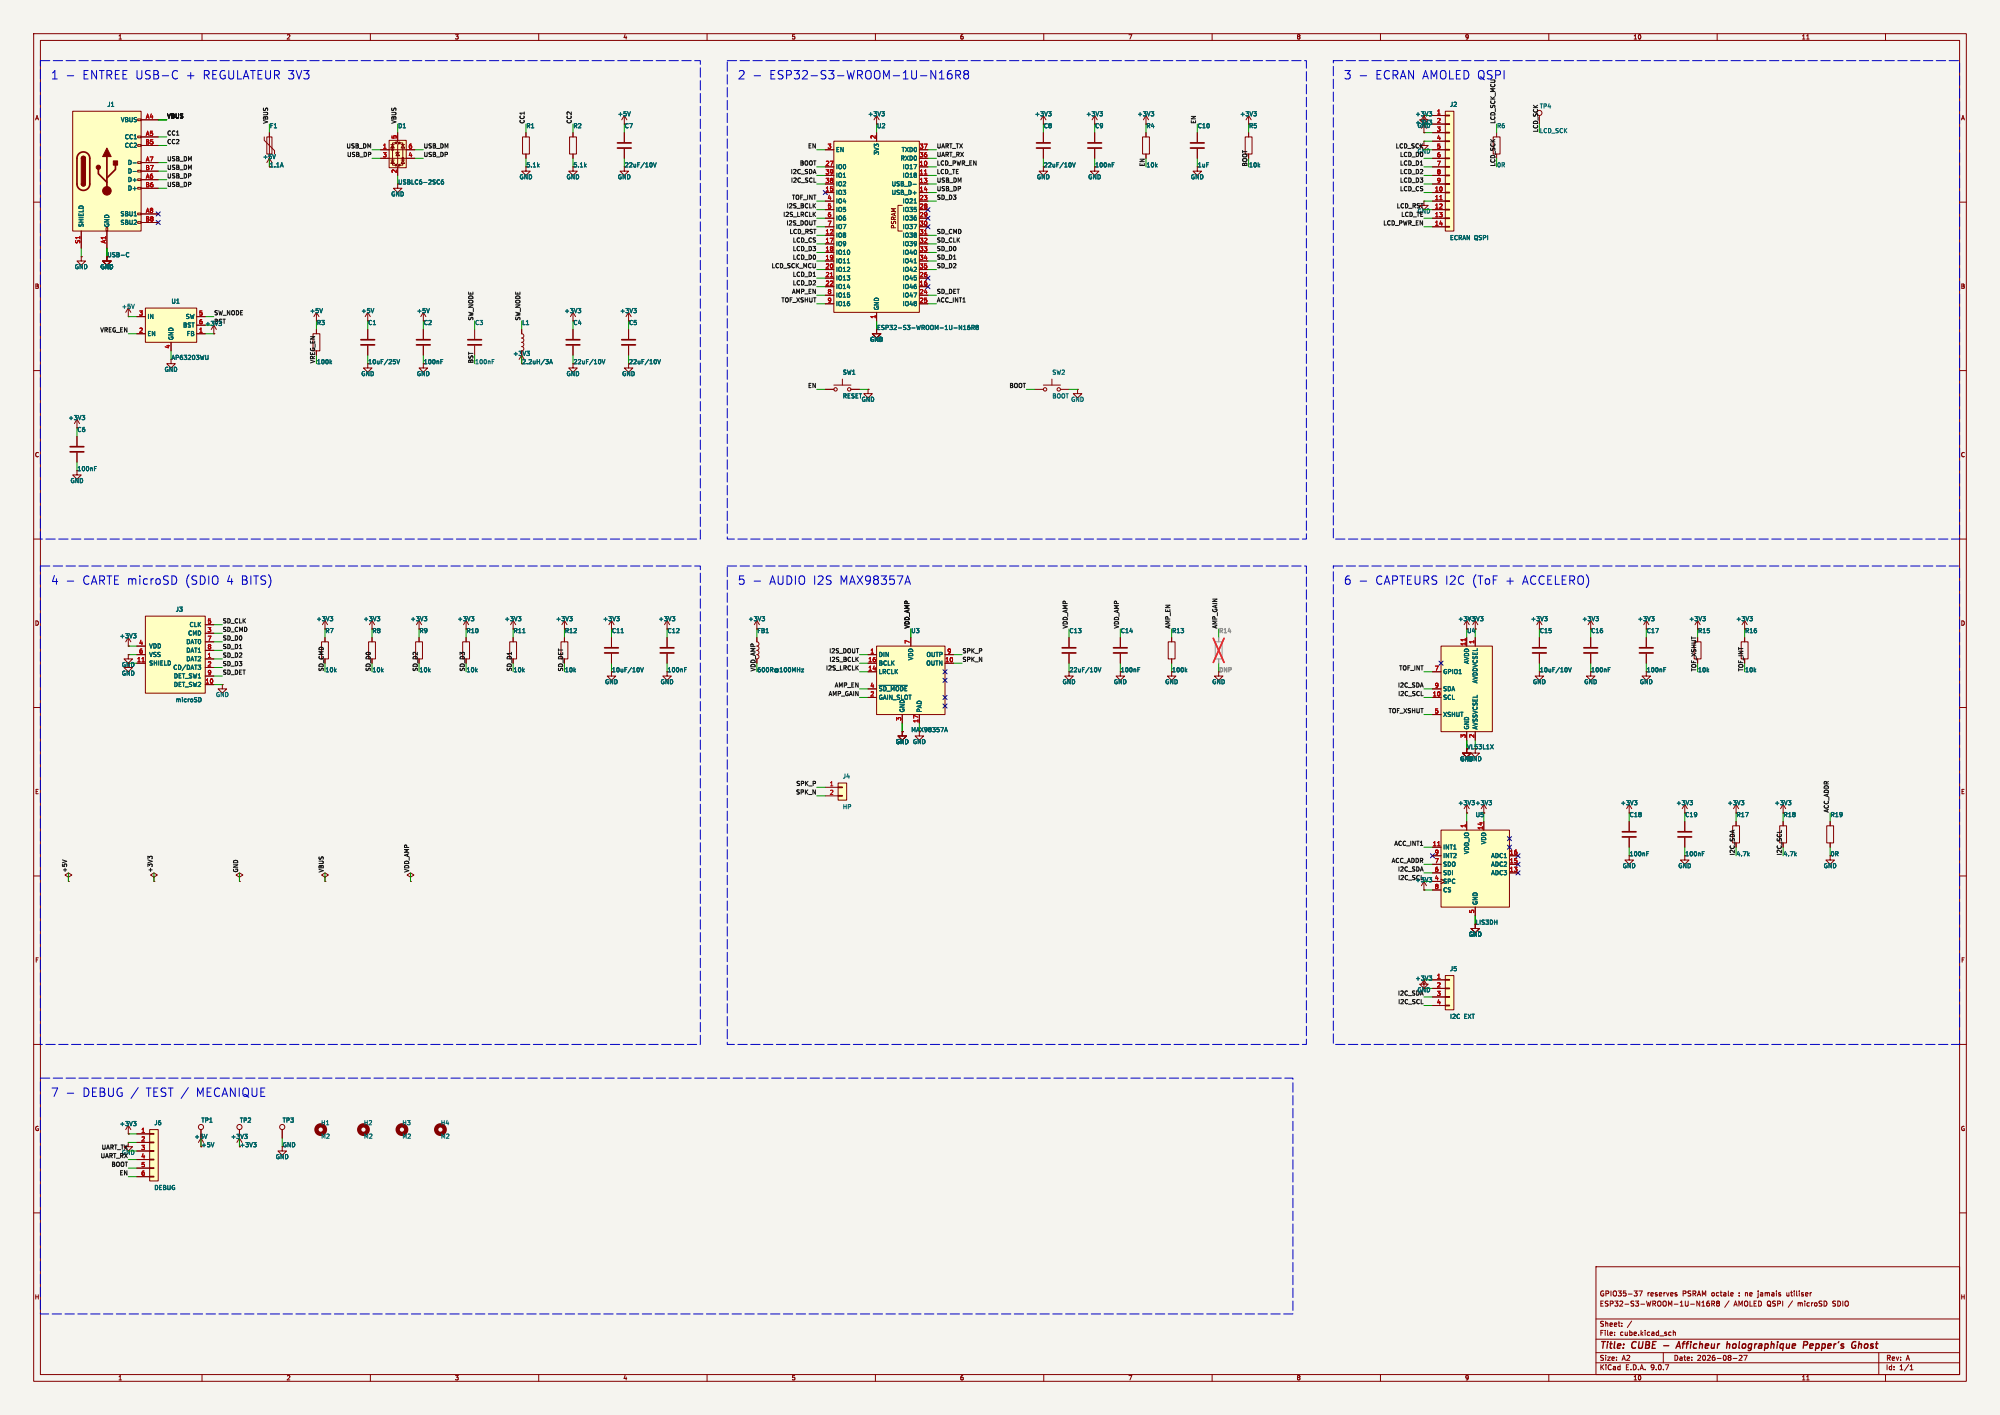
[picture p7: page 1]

4 SW 5 BST 6 FB 1 GND

4 - CARTE microSD (SDIO 4 BITS)

7 PAD 17 OUTP 9 OUTN 10 U3 MAX98357A GND

7 PAD 17 OUTP 9 OUTN 10 GND GND

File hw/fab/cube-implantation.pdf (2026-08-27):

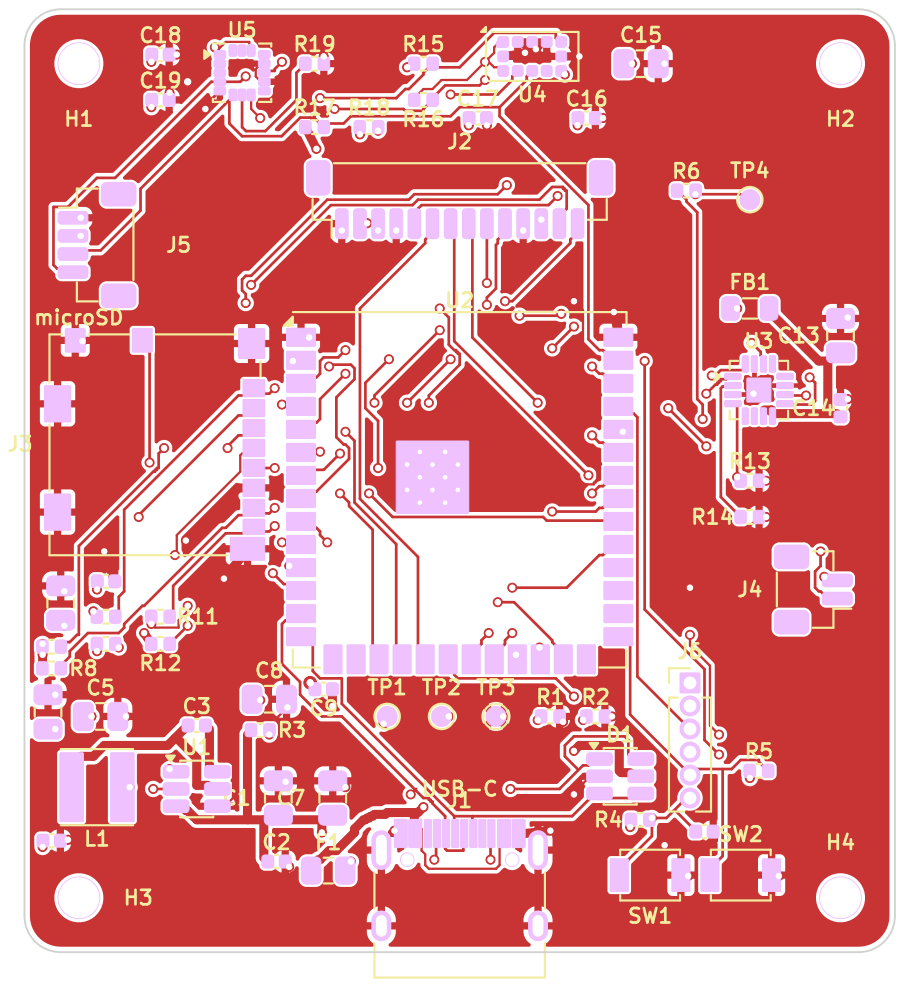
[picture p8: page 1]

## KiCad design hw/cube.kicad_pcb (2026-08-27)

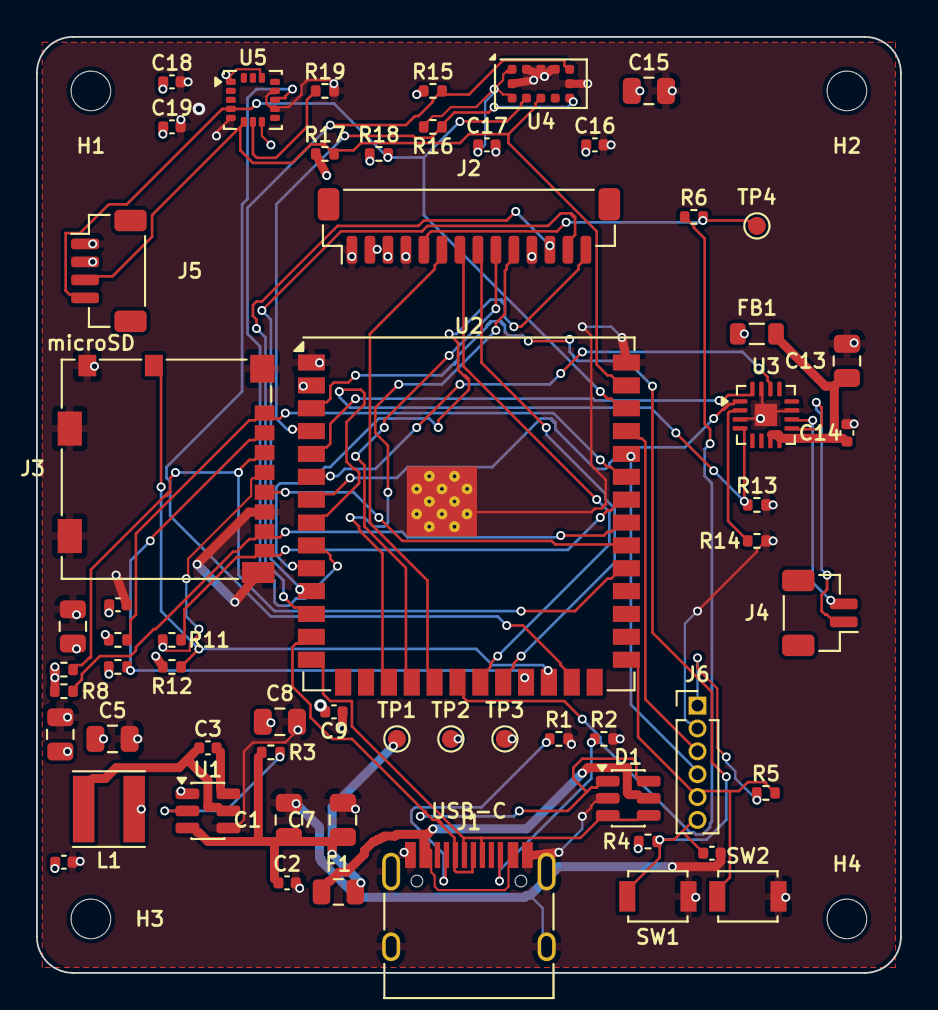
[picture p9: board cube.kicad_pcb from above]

Board: 4 copper layers, 48.0 x 52.0 mm, 63 parts (0 on the bottom side), 46 nets.

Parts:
C1: 10uF/25V; C_0805_2012Metric
C2, C3, C6, C9, C12, C14, C16, C17, C18, C19: 100nF; C_0402_1005Metric
C4, C5, C7, C8, C13: 22uF/10V; C_0805_2012Metric
C10: 1uF; C_0402_1005Metric
C11, C15: 10uF/10V; C_0805_2012Metric
D1: USBLC6-2SC6; SOT-23-6
F1: 1.1A; Fuse_0805_2012Metric
FB1: 600R@100MHz; L_0805_2012Metric
H1, H2, H3, H4: M2; MountingHole_2.2mm_M2
J1: USB-C; USB_C_Receptacle_HRO_TYPE-C-31-M-12
J2: ECRAN QSPI; JST_SH_BM14B-SRSS-TB_1x14-1MP_P1.00mm_Vertical
J3: microSD; microSD_HC_Molex_104031-0811
J4: HP; JST_SH_BM02B-SRSS-TB_1x02-1MP_P1.00mm_Vertical
J5: I2C EXT; JST_SH_BM04B-SRSS-TB_1x04-1MP_P1.00mm_Vertical
J6: DEBUG; PinHeader_1x06_P1.27mm_Vertical
L1: 2.2uH/3A; L_Taiyo-Yuden_NR-40xx
R1, R2: 5.1k; R_0402_1005Metric
R3, R13: 100k; R_0402_1005Metric
R4, R5, R7, R8, R9, R10, R11, R12, R15, R16: 10k; R_0402_1005Metric
R6, R19: 0R; R_0402_1005Metric
R14: DNP; R_0402_1005Metric
R17, R18: 4.7k; R_0402_1005Metric
SW1: RESET; SW_SPST_B3U-1000P
SW2: BOOT; SW_SPST_B3U-1000P
TP1: +5V; TestPoint_Pad_D1.0mm
TP2: +3V3; TestPoint_Pad_D1.0mm
TP3: GND; TestPoint_Pad_D1.0mm
TP4: LCD_SCK; TestPoint_Pad_D1.0mm
U1: AP63203WU; TSOT-23-6
U2: ESP32-S3-WROOM-1U-N16R8; ESP32-S3-WROOM-1U
U3: MAX98357A; TQFN-16-1EP_3x3mm_P0.5mm_EP1.23x1.23mm
U4: VL53L1X; ST_VL53L1x
U5: LIS3DH; LGA-16_3x3mm_P0.5mm_LayoutBorder3x5y

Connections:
+3V3: C4.1, C5.1, C6.1, C8.1, C9.1, C11.1, C12.1, C15.1, C16.1, C17.1, C18.1, C19.1, FB1.1, J2.2, J2.3, J3.4, J5.2, J6.1, L1.2, R4.1, R5.1, R7.1, R8.1, R9.1, R10.1, R11.1, R12.1, R15.1, R16.1, R17.1, R18.1, TP2.1, U1.1, U2.2, U4.1, U4.11, U5.1, U5.8, U5.14
+5V: C1.1, C2.1, C7.1, F1.2, R3.1, TP1.1, U1.3
/ACC_ADDR: R19.1, U5.7
/ACC_INT1: U2.25, U5.11
/AMP_EN: R13.1, U2.8, U3.4
/AMP_GAIN: R14.1, U3.2
/BOOT: J6.5, R5.2, SW2.1, U2.27
/BST: C3.2, U1.6
/CC1: J1.A5, R1.1
/CC2: J1.B5, R2.1
/EN: C10.1, J6.6, R4.2, SW1.1, U2.3
/I2C_SCL: J5.4, R18.2, U2.38, U4.10, U5.4
/I2C_SDA: J5.3, R17.2, U2.39, U4.9, U5.6
/I2S_BCLK: U2.5, U3.16
/I2S_DOUT: U2.7, U3.1
/I2S_LRCLK: U2.6, U3.14
/LCD_CS: J2.10, U2.17
/LCD_D0: J2.6, U2.19
/LCD_D1: J2.7, U2.21
/LCD_D2: J2.8, U2.22
/LCD_D3: J2.9, U2.18
/LCD_PWR_EN: J2.14, U2.10
/LCD_RST: J2.12, U2.12
/LCD_SCK: J2.5, R6.2, TP4.1
/LCD_SCK_MCU: R6.1, U2.20
/LCD_TE: J2.13, U2.11
/SD_CLK: J3.5, U2.32
/SD_CMD: J3.3, R7.2, U2.31
/SD_D0: J3.7, R8.2, U2.33
/SD_D1: J3.8, R11.2, U2.34
/SD_D2: J3.1, R9.2, U2.35
/SD_D3: J3.2, R10.2, U2.23
/SD_DET: J3.9, R12.2, U2.24
/SPK_N: J4.2, U3.10
/SPK_P: J4.1, U3.9
/SW_NODE: C3.1, L1.1, U1.5
/TOF_INT: R16.2, U2.4, U4.7
/TOF_XSHUT: R15.2, U2.9, U4.5
/UART_RX: J6.4, U2.36
/UART_TX: J6.3, U2.37
/USB_DM: D1.1, D1.6, J1.A7, J1.B7, U2.13
/USB_DP: D1.3, D1.4, J1.A6, J1.B6, U2.14
/VBUS: D1.5, F1.1, J1.A4, J1.A9, J1.B4, J1.B9
/VDD_AMP: C13.1, C14.1, FB1.2, U3.7, U3.8
/VREG_EN: R3.2, U1.2
GND: C1.2, C2.2, C4.2, C5.2, C6.2, C7.2, C8.2, C9.2, C10.2, C11.2, C12.2, C13.2, C14.2, C15.2, C16.2, C17.2, C18.2, C19.2, D1.2, J1.A1, J1.A12, J1.B1, J1.B12, J1.S1, J2.1, J2.4, J2.11, J3.6, J3.10, J3.11, J5.1, J6.2, R1.2, R2.2, R13.2, R14.2, R19.2, SW1.2, SW2.2, TP3.1, U1.4, U2.1, U2.40, U2.41, U3.3, U3.11, U3.15, U3.17, U4.2, U4.3, U4.4, U4.6, U4.12, U5.5, U5.10, U5.12

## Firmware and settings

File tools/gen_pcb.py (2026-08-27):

"""Genere hw/cube.kicad_pcb : empilage 4 couches, empreintes placees, nets
affectes, contour de carte, plans de masse/alimentation et serigraphie."""
import math
import os
import uuid as _uuid

import sexpr
import symlib
import fputil
import design as D
from sexpr import Sym, first

HERE = os.path.dirname(os.path.abspath(__file__))
OUT_DIR = os.path.join(os.path.dirname(HERE), "hw")

# KiCad 9 : F.Cu=0, B.Cu=2, In1.Cu=4, In2.Cu=6
LAYERS = [
    (0, "F.Cu", "signal", None),
    (4, "In1.Cu", "signal", None),   # plan de masse (voir docs/CARTE.md)
    (6, "In2.Cu", "signal", None),   # plan +3V3
    (2, "B.Cu", "signal", None),
    (9, "F.Adhes", "user", "F.Adhesive"), (11, "B.Adhes", "user", "B.Adhesive"),
    (13, "F.Paste", "user", None), (15, "B.Paste", "user", None),
    (5, "F.SilkS", "user", "F.Silkscreen"), (7, "B.SilkS", "user", "B.Silkscreen"),
    (1, "F.Mask", "user", None), (3, "B.Mask", "user", None),
    (17, "Dwgs.User", "user", "User.Drawings"), (19, "Cmts.User", "user", "User.Comments"),
    (21, "Eco1.User", "user", "User.Eco1"), (23, "Eco2.User", "user", "User.Eco2"),
    (25, "Edge.Cuts", "user", None), (27, "Margin", "user", None),
    (31, "F.CrtYd", "user", "F.Courtyard"), (29, "B.CrtYd", "user", "B.Courtyard"),
    (35, "F.Fab", "user", None), (33, "B.Fab", "user", None),
]

_seen = {}


def uid(key):
    if key not in _seen:
        _seen[key] = str(_uuid.uuid5(_uuid.NAMESPACE_URL, "cube-pcb/" + key))
    return _seen[key]


def N(v):
    return Sym(("%.6f" % v).rstrip("0").rstrip(".") if isinstance(v, float) else str(v))


def xy(x, y):
    return [Sym("xy"), N(x), N(y)]


# Les etiquettes locales du schema sont exportees par KiCad avec le prefixe de
# feuille "/". Les symboles d'alimentation, eux, sont globaux et n'en ont pas.
# On reproduit exactement cette convention pour que "Update PCB from schematic"
# ne renomme rien.
GLOBAL_NETS = {"GND", "+3V3", "+5V"}


def disp(name):
    if not name:
        return ""
    return name if name in GLOBAL_NETS else "/" + name


def net_table():
    """nom de net -> index. 0 est reserve aux pastilles non connectees."""
    nets = {"": 0}
    for i, name in enumerate(sorted(D.NETS), start=1):
        nets[name] = i
    return nets


def pad_net_map():
    """(ref, numero_pastille) -> nom de net."""
    m = {}
    for name, conns in D.NETS.items():
        for ref, pin in conns:
            m[(ref, pin)] = name
    return m


# --------------------------------------------------------------------------
# Empreintes
# --------------------------------------------------------------------------
SKIP_TOP = {Sym("version"), Sym("generator"), Sym("generator_version"),
            Sym("layer"), Sym("property"), Sym("at"), Sym("uuid"), Sym("path")}


# 0,8 mm est le minimum que JLCPCB garantit lisible ; en dessous le texte
# peut etre illisible ou simplement pas imprime.
SILK_SIZE = 0.8
SILK_THICK = 0.15


def place_silk():
    """Position de chaque reference sur la serigraphie, sans chevauchement.

    On essaie quatre cotes autour du contour de courtoisie ; si aucun ne tient,
    la reference est masquee sur la serigraphie (elle reste sur F.Fab, donc
    lisible sur le plan d'implantation).
    """
    boxes = {}
    for ref in D.PARTS:
        x, y, rot, _ = D.PCB_PLACE[ref]
        a, b, c, d = fputil.courtyard_box(D.PARTS[ref]["fp"], rot)
        boxes[ref] = (x + a, y + b, x + c, y + d)

    def hits(box, skip):
        for r, bb in boxes.items():
            if r == skip:
                continue
            if (box[0] < bb[2] and box[2] > bb[0] and
                    box[1] < bb[3] and box[3] > bb[1]):
                return True
        for bb in placed:
            if (box[0] < bb[2] and box[2] > bb[0] and
                    box[1] < bb[3] and box[3] > bb[1]):
                return True
        return False

    placed = []
    out = {}
    # les gros boitiers passent en premier : leur etiquette a la priorite
    order = sorted(D.PARTS, key=lambda r: -((boxes[r][2] - boxes[r][0]) *
                                            (boxes[r][3] - boxes[r][1])))
    for ref in order:
        x, y, rot, _ = D.PCB_PLACE[ref]
        b = boxes[ref]
        tw = len(ref) * SILK_SIZE * 0.78 + 0.2
        th = SILK_SIZE + 0.2
        cx, cy = (b[0] + b[2]) / 2, (b[1] + b[3]) / 2
        cands = [(cx, b[1] - th / 2 - 0.1), (cx, b[3] + th / 2 + 0.1),
                 (b[2] + tw / 2 + 0.1, cy), (b[0] - tw / 2 - 0.1, cy)]
        chosen = None
        for px, py in cands:
            box = (px - tw / 2, py - th / 2, px + tw / 2, py + th / 2)
            # le texte doit tenir entierement sur la carte, sinon il est rogne
            if (box[0] < D.BOARD_X + 0.2 or box[1] < D.BOARD_Y + 0.2 or
                    box[2] > D.BOARD_X + D.BOARD_W - 0.2 or
                    box[3] > D.BOARD_Y + D.BOARD_H - 0.2):
                continue
            if not hits(box, ref):
                chosen = (px - x, py - y)
                placed.append(box)
                break
        out[ref] = chosen
    return out


SILK_POS = None


def build_footprint(ref, part, x, y, rot, nets, padmap):
    src = symlib.load_footprint(part["fp"])
    fp = [Sym("footprint"), part["fp"],
          [Sym("layer"), "F.Cu"],
          [Sym("uuid"), uid("fp-" + ref)],
          [Sym("at"), N(x), N(y)] + ([N(rot)] if rot else [])]

    descr = first(src, Sym("descr"))
    tags = first(src, Sym("tags"))
    if descr:
        fp.append(descr)
    if tags:
        fp.append(tags)

    def txt_prop(name, value, ly, dy, hide=False, dx=0.0):
        p = [Sym("property"), name, value,
             [Sym("at"), N(dx), N(dy), N(0)],
             [Sym("unlocked"), Sym("yes")],
             [Sym("layer"), ly],
             ([Sym("hide"), Sym("yes")] if hide else None),
             [Sym("uuid"), uid("fpp-%s-%s" % (ref, name))],
             [Sym("effects"), [Sym("font"),
                               [Sym("size"), N(SILK_SIZE), N(SILK_SIZE)],
                               [Sym("thickness"), N(SILK_THICK)]]]]
        return [e for e in p if e is not None]

    b = fputil.courtyard_box(part["fp"], rot)
    sp = (SILK_POS or {}).get(ref)
    if sp:
        fp.append(txt_prop("Reference", ref, "F.SilkS", sp[1], dx=sp[0]))
    else:
        # aucune place libre : la reference reste sur F.Fab (plan d'implantation)
        fp.append(txt_prop("Reference", ref, "F.SilkS", b[1] - 0.7, hide=True))
    fp.append(txt_prop("Value", part["val"], "F.Fab", b[3] + 0.7, hide=True))
    fp.append(txt_prop("Footprint", part["fp"], "F.Fab", 0, hide=True))
    fp.append(txt_prop("Datasheet", "", "F.Fab", 0, hide=True))
    fp.append(txt_prop("Description", part["desc"], "F.Fab", 0, hide=True))

    attr = first(src, Sym("attr"))
    if attr:
        fp.append(attr)
    if part["dnp"]:
        fp.append([Sym("attr"), Sym("dnp")])

    pad_i = 0
    for node in src[2:]:
        if not isinstance(node, list) or node[0] in SKIP_TOP:
            continue
        if node[0] == Sym("attr"):
            continue
        if node[0] == Sym("pad"):
            pad_i += 1
            pad = [c for c in node if not (isinstance(c, list)
                                           and c[0] in (Sym("uuid"), Sym("net")))]
            # l'angle de pastille est absolu dans un .kicad_pcb
            at = first(pad, Sym("at"))
            local_a = float(at[3]) if len(at) > 3 else 0.0
            newa = (local_a + rot) % 360.0
            at_new = [Sym("at"), N(float(at[1])), N(float(at[2]))]
            if newa:
                at_new.append(N(newa))
            pad = [at_new if (isinstance(c, list) and c[0] == Sym("at")) else c for c in pad]

            netname = padmap.get((ref, str(node[1])))
            out = [Sym("pad")]
            for c in pad[1:]:
                out.append(c)
            if netname:
                out.append([Sym("net"), N(nets[netname]), disp(netname)])
            out.append([Sym("uuid"), uid("pad-%s-%s-%d" % (ref, node[1], pad_i))])
            fp.append(out)
        else:
            fp.append(node)
    return fp


# --------------------------------------------------------------------------
# Graphiques
# --------------------------------------------------------------------------
def gr_line(p1, p2, layer, width, key):
    return [Sym("gr_line"),
            [Sym("start"), N(p1[0]), N(p1[1])],
            [Sym("end"), N(p2[0]), N(p2[1])],
            [Sym("stroke"), [Sym("width"), N(width)], [Sym("type"), Sym("default")]],
            [Sym("layer"), layer], [Sym("uuid"), uid(key)]]


def gr_arc(s, m, e, layer, width, key):
    return [Sym("gr_arc"),
            [Sym("start"), N(s[0]), N(s[1])],
            [Sym("mid"), N(m[0]), N(m[1])],
            [Sym("end"), N(e[0]), N(e[1])],
            [Sym("stroke"), [Sym("width"), N(width)], [Sym("type"), Sym("default")]],
            [Sym("layer"), layer], [Sym("uuid"), uid(key)]]


def gr_text(txt, x, y, layer, size, key, rot=0, mirror=False, thick=0.15):
    eff = [Sym("effects"), [Sym("font"), [Sym("size"), N(size), N(size)],
                            [Sym("thickness"), N(thick)]]]
    if mirror:
        eff.append([Sym("justify"), Sym("mirror")])
    return [Sym("gr_text"), txt,
            [Sym("at"), N(x), N(y)] + ([N(rot)] if rot else []),
            [Sym("layer"), layer], [Sym("uuid"), uid(key)], eff]


def board_outline():
    """Rectangle a coins arrondis sur Edge.Cuts."""
    x0, y0 = D.BOARD_X, D.BOARD_Y
    x1, y1 = D.BOARD_X + D.BOARD_W, D.BOARD_Y + D.BOARD_H
    r = D.BOARD_CORNER_R
    w = 0.1
    out = [
        gr_line((x0 + r, y0), (x1 - r, y0), "Edge.Cuts", w, "edge-n"),
        gr_line((x1, y0 + r), (x1, y1 - r), "Edge.Cuts", w, "edge-e"),
        gr_line((x1 - r, y1), (x0 + r, y1), "Edge.Cuts", w, "edge-s"),
        gr_line((x0, y1 - r), (x0, y0 + r), "Edge.Cuts", w, "edge-o"),
    ]
    k = r * (1 - math.sqrt(0.5))
    corners = [
        ((x1 - r, y0), (x1 - k, y0 + k), (x1, y0 + r), "ne"),
        ((x1, y1 - r), (x1 - k, y1 - k), (x1 - r, y1), "se"),
        ((x0 + r, y1), (x0 + k, y1 - k), (x0, y1 - r), "so"),
        ((x0, y0 + r), (x0 + k, y0 + k), (x0 + r, y0), "no"),
    ]
    for s, m, e, tag in corners:
        out.append(gr_arc(s, m, e, "Edge.Cuts", w, "edge-arc-" + tag))
    return out


def zone(net_idx, net_name, layers, poly, key, priority=0, name=""):
    z = [Sym("zone"),
         [Sym("net"), N(net_idx)],
         [Sym("net_name"), net_name],
         [Sym("layers")] + list(layers),
         [Sym("uuid"), uid(key)]]
    if name:
        z.append([Sym("name"), name])
    z.append([Sym("hatch"), Sym("edge"), N(0.5)])
    if priority:
        z.append([Sym("priority"), N(priority)])
    z += [[Sym("connect_pads"), [Sym("clearance"), N(0.2)]],
          [Sym("min_thickness"), N(0.2)],
          [Sym("filled_areas_thickness"), Sym("no")],
          [Sym("fill"), Sym("yes"),
           [Sym("thermal_gap"), N(0.3)],
           [Sym("thermal_bridge_width"), N(0.4)],
           # 0 = supprimer les ilots non relies : evite des zones orphelines
           [Sym("island_removal_mode"), N(0)]],
          [Sym("polygon"), [Sym("pts")] + [xy(px, py) for px, py in poly]]]
    return z


def build():
    nets = net_table()
    padmap = pad_net_map()

    pcb = [Sym("kicad_pcb"),
           [Sym("version"), Sym("20241229")],
           [Sym("generator"), "pcbnew"],
           [Sym("generator_version"), "9.0"],
           [Sym("general"), [Sym("thickness"), N(1.6)],
            [Sym("legacy_teardrops"), Sym("no")]],
           [Sym("paper"), "A4"],
           [Sym("title_block"),
            [Sym("title"), D.TITLE],
            [Sym("rev"), D.REV],
            [Sym("comment"), Sym("1"), "48 x 52 mm - 4 couches - F.Cu / GND / PWR / B.Cu"]]]

    lay = [Sym("layers")]
    for num, nm, typ, usr in LAYERS:
        e = [N(num), nm, Sym(typ)]
        if usr:
            e.append(usr)
        lay.append(e)
    pcb.append(lay)

    pcb.append([Sym("setup"),
                [Sym("pad_to_mask_clearance"), N(0.05)],
                [Sym("aux_axis_origin"), N(D.BOARD_X), N(D.BOARD_Y + D.BOARD_H)],
                [Sym("allow_soldermask_bridges_in_footprints"), Sym("no")],
                [Sym("tenting"), Sym("front"), Sym("back")]])

    for name, idx in sorted(nets.items(), key=lambda kv: kv[1]):
        pcb.append([Sym("net"), N(idx), disp(name)])

    global SILK_POS
    SILK_POS = place_silk()
    for ref, part in D.PARTS.items():
        x, y, rot, _ = D.PCB_PLACE[ref]
        pcb.append(build_footprint(ref, part, x, y, rot, nets, padmap))

    pcb.extend(board_outline())

    # ---- plans de cuivre ----
    m = 0.3
    x0, y0 = D.BOARD_X + m, D.BOARD_Y + m
    x1, y1 = D.BOARD_X + D.BOARD_W - m, D.BOARD_Y + D.BOARD_H - m
    full = [(x0, y0), (x1, y0), (x1, y1), (x0, y1)]
    pcb.append(zone(nets["GND"], disp("GND"), ["In1.Cu"], full, "z-gnd-in1",
                    name="Plan de masse"))
    pcb.append(zone(nets["+3V3"], disp("+3V3"), ["In2.Cu"], full, "z-3v3-in2",
                    name="Plan +3V3"))
    pcb.append(zone(nets["GND"], disp("GND"), ["F.Cu"], full, "z-gnd-f",
                    name="Remplissage masse dessus"))
    pcb.append(zone(nets["GND"], disp("GND"), ["B.Cu"], full, "z-gnd-b",
                    name="Remplissage masse dessous"))

    # ---- serigraphie ----
    cx = D.BOARD_X + D.BOARD_W / 2
    # au-dessus de l'empreinte USB-C, sinon le texte est traverse par ses trous
    pcb.append(gr_text("CUBE  rev %s" % D.REV, cx, D.BOARD_Y + D.BOARD_H - 12.5,
                       "B.SilkS", 1.4, "silk-title", mirror=True))
    pcb.append(gr_text("GPIO35-37 = PSRAM : NE PAS UTILISER",
                       cx, D.BOARD_Y + D.BOARD_H - 10.6,
                       "B.SilkS", 0.8, "silk-warn", mirror=True))
    # brochage du connecteur ecran, au dos
    jx, jy, _, _ = D.PCB_PLACE["J2"]
    for i, (pin, sig) in enumerate(D.J2_PINOUT):
        col, row = divmod(i, 7)
        pcb.append(gr_text("%d %s" % (pin, sig),
                           jx - 13 + col * 14, jy + 8 + row * 1.9,
                           "B.SilkS", 0.8, "silk-j2-%d" % pin, mirror=True))
    pcb.append(gr_text("microSD", 103.0, 117.0, "F.SilkS", 0.8, "silk-sd"))
    pcb.append(gr_text("USB-C", cx, 143.0, "F.SilkS", 0.8, "silk-usb"))

    pcb.extend(routing(nets))
    pcb.append([Sym("embedded_fonts"), Sym("no")])
    return pcb


def routing(nets):
    """Pistes et vias produits par router.py, s'ils existent."""
    import json
    path = os.path.join(OUT_DIR, "routes.json")
    if not os.path.isfile(path):
        return []
    with open(path, encoding="utf-8") as fh:
        data = json.load(fh)
    lname = {0: "F.Cu", 1: "B.Cu"}
    out = []
    for i, entry in enumerate(data["tracks"]):
        a, b, L, net, w = entry
        # L peut etre un index historique (0/1) ou directement un nom de couche,
        # ce qui permet de conserver une piste tracee sur une couche interne.
        L = lname[L] if isinstance(L, int) else L
        out.append([Sym("segment"),
                    [Sym("start"), N(a[0]), N(a[1])],
                    [Sym("end"), N(b[0]), N(b[1])],
                    [Sym("width"), N(w)],
                    [Sym("layer"), L],
                    [Sym("net"), N(nets[net])],
                    [Sym("uuid"), uid("seg-%d" % i)]])
    for i, entry in enumerate(data["vias"]):
        p, net = entry[0], entry[1]
        size = entry[2] if len(entry) > 2 else 0.5
        drill = entry[3] if len(entry) > 3 else 0.3
        out.append([Sym("via"),
                    [Sym("at"), N(p[0]), N(p[1])],
                    [Sym("size"), N(size)],
                    [Sym("drill"), N(drill)],
                    [Sym("layers"), "F.Cu", "B.Cu"],
                    [Sym("net"), N(nets[net])],
                    [Sym("uuid"), uid("via-%d" % i)]])
    return out


def main():
    os.makedirs(OUT_DIR, exist_ok=True)
    pcb = build()
    path = os.path.join(OUT_DIR, D.PROJECT + ".kicad_pcb")
    with open(path, "w", encoding="utf-8") as fh:
        fh.write(sexpr.dump(pcb) + "\n")
    print("ecrit %s  (%d octets)" % (path, os.path.getsize(path)))


if __name__ == "__main__":
    main()

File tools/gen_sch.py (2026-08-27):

"""Genere hw/cube.kicad_sch a partir de design.py.

Style : chaque broche recoit un troncon de fil court termine par une etiquette
de net (ou un symbole d'alimentation). C'est le style "net labels", lisible et
surtout genere de facon deterministe et verifiable.
"""
import os
import uuid as _uuid
import datetime

import sexpr
import symlib
import design as D
from sexpr import Sym, find, first

HERE = os.path.dirname(os.path.abspath(__file__))
OUT_DIR = os.path.join(os.path.dirname(HERE), "hw")
GRID = 1.27
STUB = 2.54          # longueur du troncon de fil sur chaque broche
FONT = 1.27

_seen_uuid = {}


def uid(key=None):
    """UUID stable si une cle est fournie -> regeneration reproductible."""
    if key is None:
        return str(_uuid.uuid4())
    if key not in _seen_uuid:
        _seen_uuid[key] = str(_uuid.uuid5(_uuid.NAMESPACE_URL, "cube/" + key))
    return _seen_uuid[key]


def snap(v):
    return round(round(v / GRID) * GRID, 4)


# --------------------------------------------------------------------------
# Symboles
# --------------------------------------------------------------------------
def build_custom_symbol(name, spec):
    """Construit un symbole KiCad pour le lecteur microSD maison."""
    left = [p for p in spec["pins"] if p[3] == "L"]
    right = [p for p in spec["pins"] if p[3] == "R"]
    rows = max(len(left), len(right))
    half_h = (rows + 1) * GRID
    hw = 8.89  # demi-largeur du corps

    body = [Sym("symbol"), name + "_0_1",
            [Sym("rectangle"),
             [Sym("start"), Sym("%g" % -hw), Sym("%g" % half_h)],
             [Sym("end"), Sym("%g" % hw), Sym("%g" % -half_h)],
             [Sym("stroke"), [Sym("width"), Sym("0.254")], [Sym("type"), Sym("default")]],
             [Sym("fill"), [Sym("type"), Sym("background")]]]]

    unit = [Sym("symbol"), name + "_1_1"]
    for side, lst, xpos, ang in (("L", left, -hw - 2.54, 0), ("R", right, hw + 2.54, 180)):
        y = (len(lst) - 1) * GRID
        for num, pname, ptype, _ in lst:
            unit.append([
                Sym("pin"), Sym(ptype), Sym("line"),
                [Sym("at"), Sym("%g" % xpos), Sym("%g" % y), Sym(str(ang))],
                [Sym("length"), Sym("2.54")],
                [Sym("name"), pname, [Sym("effects"), [Sym("font"),
                    [Sym("size"), Sym("1.27"), Sym("1.27")]]]],
                [Sym("number"), num, [Sym("effects"), [Sym("font"),
                    [Sym("size"), Sym("1.27"), Sym("1.27")]]]],
            ])
            y -= 2 * GRID

    sym = [Sym("symbol"), name,
           [Sym("pin_names"), [Sym("offset"), Sym("1.016")]],
           [Sym("exclude_from_sim"), Sym("no")],
           [Sym("in_bom"), Sym("yes")],
           [Sym("on_board"), Sym("yes")]]
    for pname, pval, hide in (("Reference", "J", False), ("Value", name, False),
                              ("Footprint", spec["fp"], True), ("Datasheet", "", True),
                              ("Description", spec["desc"], True)):
        eff = [Sym("effects"), [Sym("font"), [Sym("size"), Sym("1.27"), Sym("1.27")]]]
        if hide:
            eff.append([Sym("hide"), Sym("yes")])
        sym.append([Sym("property"), pname, pval,
                    [Sym("at"), Sym("0"), Sym("%g" % (half_h + 2.54)), Sym("0")], eff])
    sym.append(body)
    sym.append(unit)
    return sym


def lib_symbol_node(lib, name):
    """Definition complete d'un symbole, renommee 'Lib:Name' pour lib_symbols."""
    if lib == "cube":
        node = build_custom_symbol(name, D.CUSTOM_SYMBOLS[name])
    else:
        node = symlib.get_symbol(lib, name)
    out = [Sym("symbol"), "%s:%s" % (lib, name)]
    for c in node[2:]:
        out.append(c)
    return out


def sym_pins(lib, name):
    """[(numero, nom, type, (sx, sy), angle)] en coordonnees symbole."""
    node = lib_symbol_node(lib, name)
    res = []
    for u in find(node, Sym("symbol")):
        for p in find(u, Sym("pin")):
            at = first(p, Sym("at"))
            res.append((first(p, Sym("number"))[1], first(p, Sym("name"))[1],
                        str(p[1]), (float(at[1]), float(at[2])),
                        int(float(at[3])) if len(at) > 3 else 0))
    return res


def sym_bbox(lib, name):
    """Boite englobante approximative (corps + broches) en coordonnees symbole."""
    node = lib_symbol_node(lib, name)
    xs, ys = [], []

    def scan(n):
        if not isinstance(n, list) or not n:
            return
        tag = n[0]
        if tag in (Sym("start"), Sym("end"), Sym("mid"), Sym("center"), Sym("xy")):
            try:
                xs.append(float(n[1])); ys.append(float(n[2]))
            except (ValueError, IndexError):
                pass
        for c in n:
            if isinstance(c, list):
                scan(c)

    for u in find(node, Sym("symbol")):
        for g in u[2:]:
            if isinstance(g, list) and g[0] != Sym("pin"):
                scan(g)
        for p in find(u, Sym("pin")):
            at = first(p, Sym("at"))
            xs.append(float(at[1])); ys.append(float(at[2]))
    if not xs:
        xs, ys = [-1.27, 1.27], [-1.27, 1.27]
    return min(xs), min(ys), max(xs), max(ys)


def pin_abs(part_xy, sxy):
    """Broche en coordonnees schema (l'axe Y du symbole est inverse)."""
    return (part_xy[0] + sxy[0], part_xy[1] - sxy[1])


# angle de broche -> (direction du troncon, angle d'etiquette)
STUB_DIR = {0: ((-1, 0), 180), 180: ((1, 0), 0), 90: ((0, 1), 270), 270: ((0, -1), 90)}


# --------------------------------------------------------------------------
# Placement des composants dans les blocs
# --------------------------------------------------------------------------
def layout():
    """ref -> (x, y). Rangement en etageres a l'interieur de chaque bloc."""
    pos = {}
    blocks = {b[0]: b for b in D.BLOCKS}
    by_block = {}
    for ref, p in D.PARTS.items():
        by_block.setdefault(p["block"], []).append(ref)

    for bid, refs in by_block.items():
        _, _, bx, by, bw, bh = blocks[bid]
        cx, cy = bx + 6, by + 12          # marge interne, sous le titre
        row_h = 0
        for ref in refs:
            p = D.PARTS[ref]
            x0, y0, x1, y1 = sym_bbox(p["lib"], p["sym"])
            pins = sym_pins(p["lib"], p["sym"])
            angs = {a for *_, a in pins}
            # marge pour les etiquettes de net
            ml = 23 if 0 in angs else 3
            mr = 23 if 180 in angs else 3
            mt = 9 if 270 in angs else 3
            mb = 9 if 90 in angs else 3
            w = (x1 - x0) + ml + mr
            h = (y1 - y0) + mt + mb
            if cx + w > bx + bw - 4 and cx > bx + 6:
                cx = bx + 6
                cy += row_h + 6
                row_h = 0
            # origine du symbole = coin haut-gauche de la cellule + marges
            pos[ref] = (snap(cx + ml - x0), snap(cy + mt + y1))
            cx += w + 6
            row_h = max(row_h, h)
    return pos
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

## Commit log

2026-08-27 chore: initialise le depot, les licences et les regles d'ignore
    Double licence assumee : MIT pour la chaine de generation (tools/), et
    CERN-OHL-S-2.0 pour le materiel (schema, PCB, fabrication). Ce sont deux
    natures de travail differentes, une seule licence ne conviendrait ni a l'une
    ni a l'autre.
    Le .gitignore exclut notamment *.kicad_prl (etat de fenetre local, source de
    conflits garantie) et hw/fab/gerber/, redondant avec l'archive zip.
    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
2026-08-27 feat(tools): lecteur et ecrivain de S-expressions KiCad
    Ecrit a la main plutot que d'ajouter une dependance : le format est simple, et
    cela garde la chaine sans aucune dependance externe. Les formes sans liste
    imbriquee restent sur une ligne, ce qui rend les fichiers generes lisibles en
    diff.
2026-08-27 feat(tools): acces aux bibliotheques officielles KiCad 9
    kicadpath localise KiCad sans chemin code en dur : variables d'environnement,
    puis PATH, puis emplacements habituels par plateforme.
    symlib resout l'heritage 'extends' des symboles ; fputil calcule la geometrie
    des empreintes. La rotation suit la convention KiCad (sens antihoraire a
    l'ecran alors que l'axe Y pointe vers le bas), verifiee sur les projets de
    demonstration livres avec KiCad.
2026-08-27 feat(design): decrit la carte — 63 composants, 46 nets, 223 connexions
    design.py est la source unique de verite du projet : composants, netlist,
    placement, plus les tables documentaires (affectation des GPIO, brochage du
    connecteur ecran). Tout le reste en decoule et se regenere.
    Choix materiels notables, chacun motive en commentaire :
    - ESP32-S3-WROOM-1U-N16R8 : PSRAM octale conservee, antenne deportee ;
    - GPIO35/36/37 volontairement absents de la netlist, la PSRAM octale les
    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
2026-08-27 feat(tools): genere le projet KiCad et le schema
    Le schema est produit en style 'net labels' : chaque broche recoit un troncon
    de fil court termine par une etiquette. C'est deterministe et verifiable, la
    ou un routage de fils genere serait fragile et illisible.
    Le lecteur microSD Molex 104031-0811 recoit un symbole maison : le
    SD_Card_Receptacle de KiCad suit la numerotation SD pleine taille et ne
    s'apparie pas aux empreintes microSD.
2026-08-27 feat(tools): solveur de placement par relaxation sous contraintes
    Chaque composant a une position souhaitee et, pour les connecteurs de bord,
    un verrou. Une relaxation iterative ecarte les contours de courtoisie qui se
    chevauchent, avec un ressort de rappel vers l'ancre dont la raideur decroit
    au fil des iterations pour sortir des minima locaux.
    Converge a 0 chevauchement et 0 debordement sur les 63 composants.
2026-08-27 feat(tools): routeur labyrinthe et couture des plans de masse
    Dijkstra 8 directions sur une grille de 0,1 mm, deux couches de signal, les
    deux couches internes etant des plans (masse et +3V3). Quatre passes avec
    reordonnancement : les nets en echec repassent en tete a la tentative
    suivante.
    Trois pieges resolus en cours de route, chacun trouve par le DRC :
    - l'inflation d'un obstacle doit inclure la demi-largeur de la piste que l'on
    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
2026-08-27 feat(tools): genere le PCB 4 couches et remplit les plans
    Empilage F.Cu / plan de masse / plan +3V3 / B.Cu : le bus QSPI de l'ecran
    court sur F.Cu directement au-dessus du plan de masse, ce qui lui donne un
    chemin de retour court.
    Le placement des references de serigraphie evite les collisions et le bord de
    carte ; les cinq qui ne tiennent nulle part restent sur F.Fab, donc lisibles
    sur le plan d'implantation.
    fill_zones.py appelle le moteur de remplissage officiel de KiCad. Sans cette
    etape, kicad-cli voit les zones vides et signale a tort toutes les pastilles
    de masse comme non connectees — 95 fausses alertes contre 4 vraies.
    [gen_pcb.py]
2026-08-27 test: verifie la conception et verrouille l'etat de la CAO
    validate.py : 14 controles. Les plus utiles confrontent design.py aux
    bibliotheques KiCad (chaque broche cablee existe-t-elle vraiment ? aucune
    broche laissee sans net ni no-connect ?) et verifient que la documentation
    generee n'a pas derive du schema.
    Ce dernier controle a immediatement trouve un vrai ecart : la table des GPIO
    annoncait LCD_SCK sur IO12 alors que la netlist y porte LCD_SCK_MCU, la
    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
2026-08-27 feat(tools): documentation et sorties de fabrication
    gen_docs produit docs/CARTE.md depuis design.py, donc la fiche technique ne
    peut pas deriver du schema. Elle inclut les cotes exprimees depuis le coin de
    la carte, directement exploitables pour dessiner le boitier.
    gen_fab produit gerbers, percage, fichier de placement, modele STEP et rendus.
    Les rendus destines au README sont a fond transparent pour rester lisibles en
    theme clair comme en theme sombre.
2026-08-27 feat(hw): projet KiCad genere, verifie et route
    Circuit imprime 48 x 52 mm, 4 couches, composants sur une seule face.
    Etat verifie a ce commit :
    - ERC : 0 erreur (1 avertissement, le pad thermique du MAX98357A est type
    'Unspecified' dans la bibliotheque KiCad officielle) ;
    - netlist exportee comparee a l'intention : 223/223, 0 divergence ;
    - parite schema/PCB verifiee par KiCad : 0 ecart ;
    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
    [cube-bom.csv, cube.kicad_pcb, cube.kicad_sch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]
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2026-08-27 docs: README, banniere animee, fiche technique et guide de contribution
    La banniere est un SVG anime ecrit a la main (SMIL), decline en variante
    claire et sombre via <picture> : elle represente le montage optique lui-meme —
    dalle, cube separateur, lame a 45 degres, rayons et image virtuelle — plutot
    qu'un bandeau decoratif.
    Le README annonce explicitement que la carte n'a jamais ete fabriquee ni
    testee physiquement. Tout ce qui y est affirme est verifie en CAO, et rien de
    plus.
2026-08-27 docs: retire le badge CI et expose les verifications reellement obtenues
    Le workflow est correct mais aucun job ne peut demarrer sur ce compte pour le
    moment. Un badge affichant 'failing' laisserait croire que le projet est
    casse : on ne garde donc que des badges dont l'affirmation est verifiee, et
    chacun pointe vers le rapport qui la prouve.
    La section 'Etat d'avancement' decrit ce que la CI execute et rappelle que les
    memes commandes se lancent en local.
2026-08-27 feat(hw): carte entierement routee — 223/223 connexions
    Les 4 dernieres liaisons, autour du LIS3DH (LGA-16 au pas de 0,5 mm), ont ete
    tirees a la main dans Pcbnew. La masse de U5 passe par une piste sur In2.Cu et
    un via vers le plan : cela cree une fente courte dans le plan +3V3, dans un
    coin qui ne consomme que des microamperes, donc sans consequence.
    tools/import_routes.py recapture ce cuivre dans routes.json : le routage
    manuel fait desormais partie du pipeline au lieu d'etre perdu a la prochaine
    generation. Le format accepte un nom de couche et la taille reelle des vias,
    ce qu'exigeaient la piste sur couche interne et les vias 0,7/0,35.
    Corrections associees, toutes signalees par le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
    [cube-bom.csv, cube.kicad_pcb, cube.kicad_sch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]

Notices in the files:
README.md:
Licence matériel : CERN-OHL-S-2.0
